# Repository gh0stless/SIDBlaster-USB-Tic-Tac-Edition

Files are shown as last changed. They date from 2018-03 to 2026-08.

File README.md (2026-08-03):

# SIDBlaster-USB Tic Tac Edition

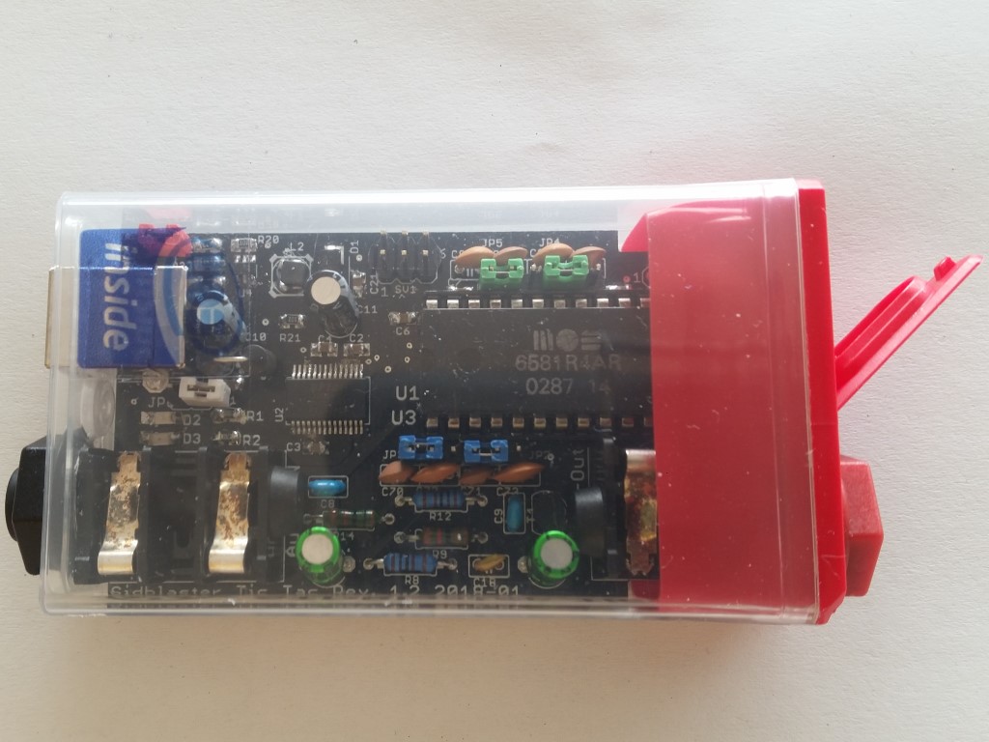
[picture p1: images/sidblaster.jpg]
SIDBlaster-USB Tic Tac Edition


**Open-source USB hardware for a genuine MOS 6581/8582 SID chip** - C64 sound
on real silicon, on your PC's USB port. Small enough to fit in a "Tic Tac"
mint box (hence the name), it plugs into a USB port and appears to host
software as a HardSID-compatible device: play SID tunes with cycle-accurate
hardware sound, or use it as a real analog synth voice from a DAW.

- - -

## What's in the box

- A genuine SID chip (6581 or 8580/8582 - your choice, whatever you socket)
  driven by a Microchip PIC16F886 and an FTDI FT245R USB-to-parallel-FIFO
  bridge
- A 6.3mm (1/4") jack audio output, studio-ready out of the box - unlike
  most RP2040-based SID-USB alternatives
- Open PCB design (Eagle + Gerber), currently at hardware revision **1.5**
- Firmware (MPASM source + compiled HEX) for the PIC16F886
- A 3D-printable case (by tyristori)
- Full German/English assembly instructions, user manual and bill of
  materials

The [driver](https://github.com/gh0stless/SIDBlasterUSB_HardSID-emulation-driver)
supports up to **8** units side by side - handy for multi-SID setups
(stereo/triple-SID playback) and for music-instrument applications like
[AIASS](https://github.com/gh0stless/AIASS-Uno-VST) that want several
independent SID voices at once.

- - -

## Repository layout

| Folder | Contents |
|---|---|
| [`pcb/`](./pcb) | Eagle schematic/board files + Gerbers, revisions 1.2 - 1.5 |
| [`pic16f886/`](./pic16f886) | PIC16F886 firmware - MPASM source and compiled `.hex` |
| [`ftdi_template/`](./ftdi_template) | FT_PROG templates for programming the FT245R USB chip |
| [`docs/`](./docs) | Assembly instructions, user manual, bill of materials (BOM) per revision - PDF + editable ODT/ODS sources |
| [`datasheet/`](./datasheet) | MOS 6581/6582 SID and MT3608 datasheets |
| [`3d_printed_case/`](./3d_printed_case) | 3D-printable case (Blender + STL), CC BY 4.0 |
| [`exSIDBlaster/`](./exSIDBlaster) | How to convert a SIDBlaster-USB into a (single-SID) exSID |
| [`hardsid_library/`](./hardsid_library) | Plain prebuilt `hardsid` driver binaries (Win/Linux/macOS) - see below for the current source/releases |
| [`images/`](./images) | Product photos |

- - -

## Getting started

1. **Build or buy** the hardware - follow the
   [assembly instructions](./docs/assembly%20instructions.pdf) /
   [Aufbauanleitung](./docs/Aufbauanleitung.pdf) and the current
   [BOM (Rev.1.5)](./docs/bill%20of%20materials%20%28BOM%29%20Rev.1.5.pdf).
2. **Program** the PIC (firmware in [`pic16f886/`](./pic16f886)) and the
   FTDI FT245R (template in [`ftdi_template/`](./ftdi_template), via FT_PROG).
3. **Install the driver** - the FTDI D2XX driver plus the `hardsid` HardSID
   emulation library. Get an installer or the latest plain binaries from
   [crazy-midi.de](https://crazy-midi.de) or the driver's own repo, see
   below.
4. **Play something** - any HardSID-aware application (Sidplay2, ACID64,
   VICE, ...) or a purpose-built app such as
   [SIDBlaster ASID Player](https://github.com/gh0stless/SIDBlaster-ASID-Player)
   (turns it into an ASID-protocol MIDI synth) or
   [AIASS](https://github.com/gh0stless/AIASS-Uno-VST) (VST/Standalone
   instrument plugin).

Full details are in the [manual](./docs/SIDBlaster-USB%20Tic%20Tac%20Edition%20User%20Manual.pdf)
/ [Handbuch](./docs/SIDBlaster-USB%20Tic%20Tac%20Edition%20Handbuch.pdf).

- - -

## The software ecosystem

This repo covers the **hardware**. The driver and applications that make it
useful live in their own actively maintained repos:

- **[SIDBlasterUSB_HardSID-emulation-driver](https://github.com/gh0stless/SIDBlasterUSB_HardSID-emulation-driver)** -
  the `hardsid` driver (Windows/Linux/macOS), source + releases. This is
  what any HardSID-compatible application talks to - except ACID64 and
  JSIDPlay2, which bring their own onboard SIDBlaster-USB support.
- **[SIDBlasterTool](https://github.com/gh0stless/SIDBlasterTool)** -
  small device config utility (read/set a device's serial number and SID
  chip type).
- **[SIDBlaster ASID Player](https://github.com/gh0stless/SIDBlaster-ASID-Player)** -
  standalone app that turns the device into an ASID-protocol MIDI synth.
- **[AIASS-Uno-VST](https://github.com/gh0stless/AIASS-Uno-VST)** - VST/VST3/
  Standalone instrument plugin driving the SID chip directly from a DAW.
- **[libsidplayfp](https://github.com/gh0stless/libsidplayfp)** (fork) -
  adds a `sidblaster-builder` backend so any libsidplayfp-based player
  (e.g. [sidplayfp](https://github.com/gh0stless/sidplayfp)) can play SID
  tunes through real SIDBlaster-USB hardware via `hardsid`, on
  Windows and Unix (dlopen).
- **SIDBlaster NG** - a from-scratch firmware + driver stack, built on the
  exSID protocol, for the **existing** SIDBlaster-USB hardware people already
  own - not a new board. Firmware trickery (hybrid mode) runs the exSID
  protocol directly on current hardware, no cutting traces or soldering
  jumpers like the old [exSID conversion](#turning-it-into-an-exsid) needed.
  RP2040-based SID-USB devices (e.g.
  [USBSID-Pico](https://github.com/LouDnl/USBSID-Pico)) may well be where
  the present and future belong for a single device on a desk - but
  SIDBlaster's scalability is unique: several units side by side (see
  [above](#whats-in-the-box)) is exactly what music applications like
  [AIASS](https://github.com/gh0stless/AIASS-Uno-VST) want. NG is planned
  around that: active multi-device handling, hotplug, and resource
  management, not just more units bolted onto the same driver model.

Prebuilt installers for all of the above (handles driver placement,
Linux udev rule, macOS D2XX symlink, etc. for you): **[crazy-midi.de](https://crazy-midi.de)**.

- - -

## Turning it into an exSID

Want [exSID](https://github.com/jpandersen/exSID)-grade playback instead?
See [`exSIDBlaster/`](./exSIDBlaster) for a one-wire hardware hack plus a
firmware/template swap that converts a SIDBlaster-USB into a (single-SID)
exSID-compatible device, for use with e.g. JSIDPlay2. Do-it-yourself, at
your own risk.

- - -

## License

Hardware design and documentation in this repository are licensed under
**GPL v3** (see [`LICENSE`](./LICENSE)). The [`pic16f886/`](./pic16f886)
firmware is **MIT**-licensed. The 3D-printed case files are **CC BY 4.0**
(see [`3d_printed_case/`](./3d_printed_case)). The original exSID firmware
referenced in [`exSIDBlaster/`](./exSIDBlaster) is licensed by the exSID
project under **Creative Commons**, not by this repository.

- - -

## Credits

Designed by Andreas Schumm (gh0stless), crazy-midi.de, building on the
original SIDBlaster concept - whoever first came up with it, thank you,
whoever you are; your name didn't reach me, but the idea did.

Thanks to Stein Pedersen for the original `hardsid` driver, Wilfred Bos for
his help with it and for SIDBlaster-USB support in ACID64Player, and Ken
Händel for the Linux/macOS driver port. exSID conversion notes courtesy of
the exSID project (Thibaut Varène). 3D-printed case by tyristori.

And to my long-time fiancée, Borjana Konstantinowa, for her patience with me.

Andreas Schumm (gh0stless)
contact: info@crazy-midi.de

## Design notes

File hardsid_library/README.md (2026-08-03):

Plain hardsid library binaries (no installer) for SIDBlaster-USB, currently v518 (0x0206).

For the latest version and an installer that handles system placement /
the Linux udev rule / the macOS D2XX symlink for you, see the driver's
own repo instead:

- [gh0stless/SIDBlasterUSB_HardSID-emulation-driver](https://github.com/gh0stless/SIDBlasterUSB_HardSID-emulation-driver) - source, releases, changelog
- Proper installers: [crazy-midi.de](https://crazy-midi.de)

The files here are kept only for the download links already referenced
from AIASS/SIDBlaster-ASID-Player's manuals.

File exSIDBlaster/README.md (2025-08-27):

# exSIDBlaster - a farewell gift

If you want, you can now convert your SIDBlaster into half an exSID.

You may have heard of its near-perfect playback, even of problematic tunes.
The exSID project, started by **Thibaut Varène**, is a further development of the SIDBlaster circuit with truly sophisticated firmware. It was pretty much a Linux standalone product, but later, cross-platform support was offered, at least by JSIDPlay2.

Please also note that neither I nor Thibaut take responsibility for this hack, if YOU do it it is entirely your risk.

After the conversion, you essentially have an exSID but only one SID. You can use this in JSIDPlay2 or the web version. Simply enable "Fake Stereo" and the sound will always play. 

Please note that the exSID firmware is under a Creative Commons license, so I cannot offer you a conversion. Basically, you only need to break one wire and solder another as a bridge. Cut pin 7 of the PIC with a small flat side cutter (or perhaps nail clippers). 2.: Solder a jumper from PIC pin 15 to SID socket pin 5. Then flash the new firmware (hex file) and program the new template (make sure you choose the right one!). You can find out how to do this in the SIDBlaster assembly instructions and manual. 

Theoretically, a similar conversion might work with the SIDBlaster nano, but in practice I would advise against it: The smaller package size of the PIC might not be able to cope as well with the additional thermal load caused by the overclocking.

A hardsid.dll wrapper DLL for exSID is still in the works.

Andreas

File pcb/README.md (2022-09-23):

# eagle and gerber files

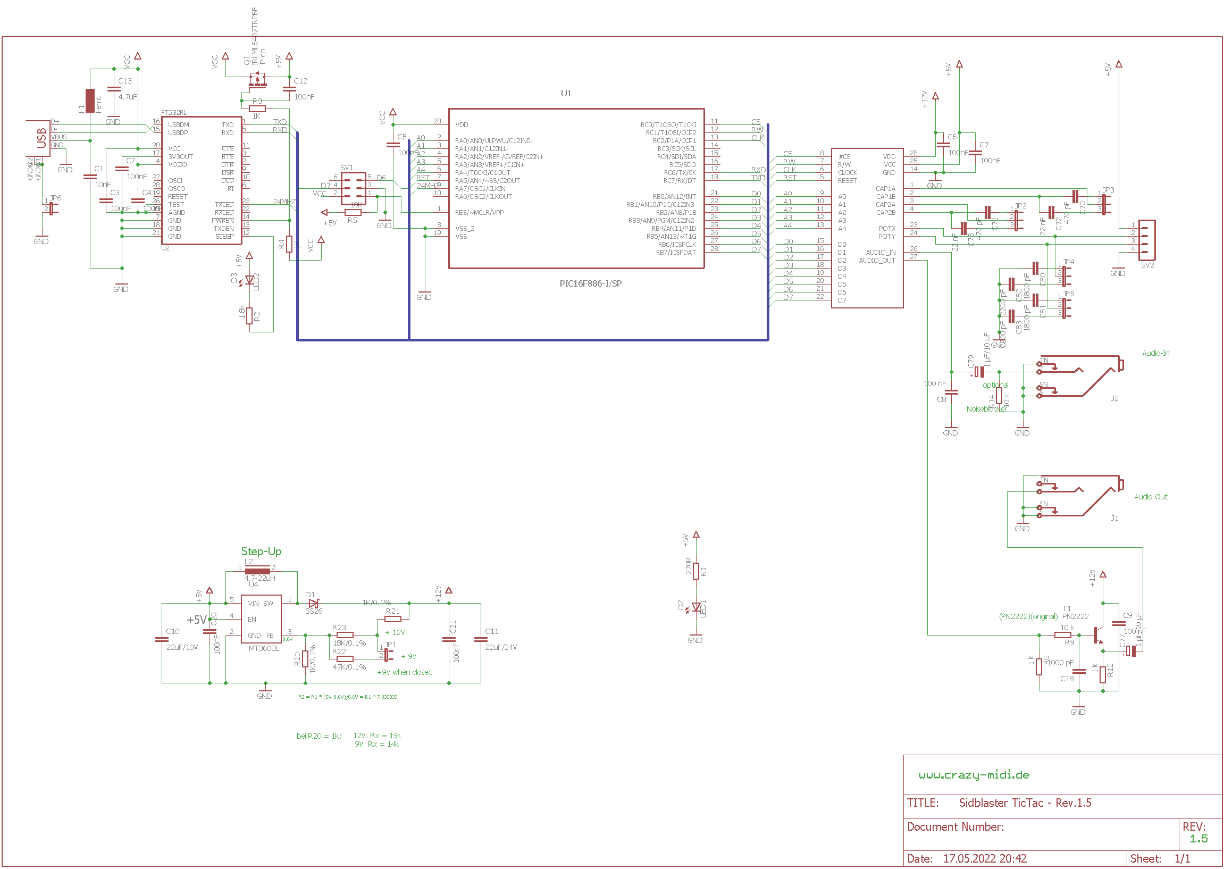
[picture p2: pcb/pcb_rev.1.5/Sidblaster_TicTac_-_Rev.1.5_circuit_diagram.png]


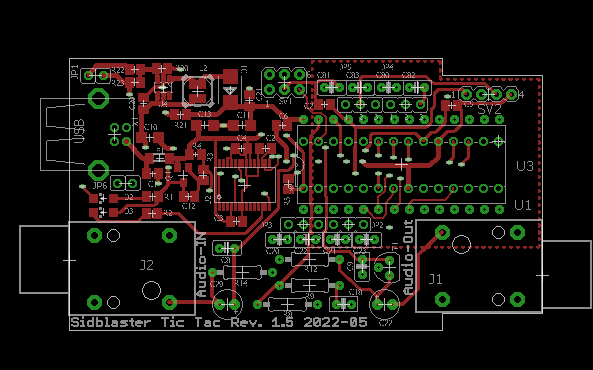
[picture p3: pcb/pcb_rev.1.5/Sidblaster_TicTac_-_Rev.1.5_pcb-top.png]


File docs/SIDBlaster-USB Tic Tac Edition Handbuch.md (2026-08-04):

SIDBlaster-USB Tic Tac Edition

# SIDBLASTER-USB — TIC TAC EDITION

*– Ein echter SID Chip auf PC oder Mac*

## HANDBUCH

von Andreas Schumm, Rev. 1.4

Copyright© 2024 [www.crazy-midi.de](http://www.crazy-midi.de/) – Lizenz: [CC BY-ND 4.0](https://creativecommons.org/licenses/by-nd/4.0/deed.de)

---

# 1. Einführung

Der SIDBlaster-USB Tic Tac ist eine hochwertige "Open-Source"-Hardware, die als kleine, an den USB-Port eines PCs oder Macs anschließbare Box die Nutzung eines echten "SID"-Soundchips zur C64-Emulation, Wiedergabe von SID-Tunes und Musikproduktion ermöglicht.

SIDBlaster-USB Tic Tac basiert auf "SIDBlaster-USB", und ist mit diesem zu 100% kompatibel.

## 1.1 Verbesserungen

- hochwertige Universalstromversorgung 9V oder 12V
- Original C64-Audioverkabelung
- Optionale Anschlussmöglichkeit für zwei Paddles
- Umschaltbare Filterkondensatoren
- Umschaltbare Kondensatoren für Paddle
- Passgenaue Platine zum Einbau in eine Tic Tac Schachtel
- Audio-Eingang
- Professionelle 6,3mm Mono-Audio-Klinkenbuchsen
- Gemütliche blaue Power-LED
- (Rev.1.2:) rote TX/RX-LED
- (Rev. 1.2 weißer Jumper zum Verbinden von GND und Shield (experimentell)
- vorbereitet für Lesezugriff (Firmware 1.1)

# 2. Allgemeine Informationen

- Plug and Play ist nicht möglich, der SIDBlaster muss vor der Verwendung in einer Anwendung an den Computer angeschlossen werden. Trennen Sie den SIDBlaster auch nicht vom Computer, bevor Sie die Anwendung beendet haben.
- Wenn Sie den SIDBlaster nicht benutzen, ist es empfehlenswert, die USB-Verbindung zu trennen, da dies die Lebensdauer des SID-Chips verlängert.
- Da ein SID-Chip Wärme erzeugt, verwenden Sie wenn möglich einen Kühlkörper auf dem Chip und sorgen Sie für ausreichende Belüftung (lassen Sie die Klappe der Tic Tac-Box offen).

# 3. Hardware-Installation

## 3.1 SID-chip-installation

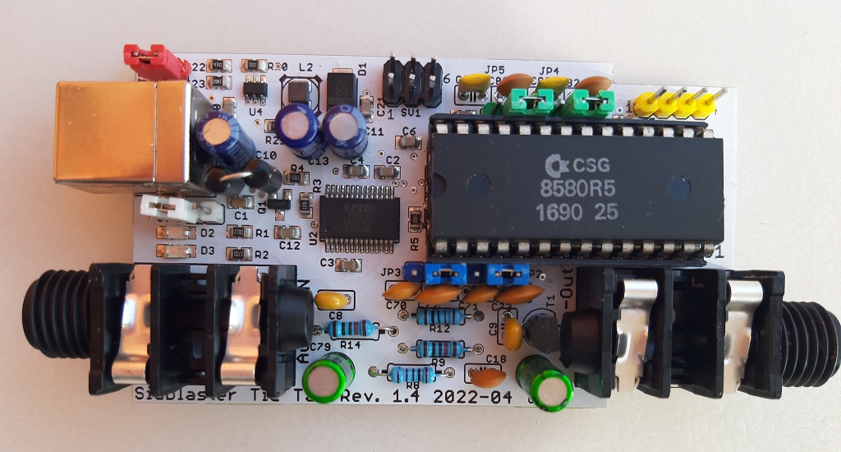
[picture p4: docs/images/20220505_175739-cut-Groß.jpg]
SID-Chip Installation


*Ein SIDBlaster-USB mit korrekt installiertem 8580*

**Warnung!** Überprüfen Sie die Spannungseinstellungen an der SIDBlaster-Hardware. Wenn Sie sie falsch einstellen, z.B. wenn Sie 12V in einen 8580 SID-Chip schicken, der mit 9V läuft, werden Sie den Chip zerstören. Wenn Sie ein Multimeter haben, **prüfen Sie die Spannung an der SID-Chip-Buchse**, um sicherzugehen. Verwenden Sie immer ESD-Schutz (z.B. ein Antistatik-Armband), um den SID-Chip und andere elektrische Komponenten nicht zu beschädigen, wenn Sie ihn in den SIDBlaster einbauen.

**Um einen SID-Chip zu entfernen**, verwenden Sie z.B. einen Schraubendreher, hebeln Sie den Chip abwechselnd heraus. Achten Sie darauf, die Platine oder die Bauteile nicht zu beschädigen.

Vor dem Einsetzen eines SID-Chips biegen Sie die Pins mit einer Zange gerade, drücken Sie vorsichtig und überprüfen Sie, dass keiner der Pins umknickt.

## 3.2 Jumper-Einstellungen

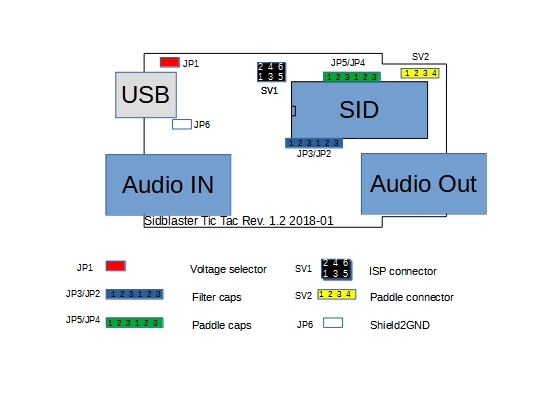
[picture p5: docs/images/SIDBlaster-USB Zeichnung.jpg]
Jumper-Übersicht


### 3.2.1 Für den 6581 SID-chip:

- JP1: muss offen sein (12V).
- JP2-JP5: Setzen Sie alle Jumper auf die linke Seite (Stifte 1-2).

### 3.2.2 Für den 8580 SID-chip:

- JP1: muss geschlossen sein (9V).
- JP2-JP5: Setzen Sie alle Jumper auf die rechte Seite (Stifte 2-3).

## 3.3 Andere Jumper der Hardware

### 3.3.1 JP6 (Weiss)

Ab Rev. 1.2 und höher. Experimentell, verbindet die USB-Abschirmung mit Masse; Sie können es benutzen, um Störgeräuschen entgegenzuwirken.

### 3.3.2 SV2:Paddle-Anschluss (gelb)

Hier haben Sie Zugriff auf die beiden A/D-Wandler des SID-Chips. Sie können z.B. 2 Drehpotentiometer als Paddles anschließen. Dies ist vor allem für Programmierer interessant. Sie können die Funktion auch mit dem SID-Objekt für Max/MSP verwenden.

| Pin | Funktion |
|---|---|
| 1 | +5V |
| 2 | POTX |
| 3 | POTY |
| 4 | GND |

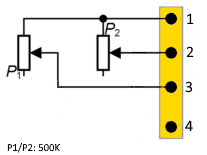
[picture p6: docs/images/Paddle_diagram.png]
Paddle-Anschluss Diagramm


### 3.3.3 SV1: ISP Connector

Verwenden Sie einen Picit 3 Programmer, um den Flash-Speicher des Mikrocontrollers zu programmieren. Als Software wird MPLAB IPE verwendet.

| Pin | Funktion |
|---|---|
| 1 | MCLR/VPP |
| 2 | +5V |
| 3 | GND |
| 4 | PGD (ICSPDAT) |
| 5 | PGC (ICSPCLK) |
| 6 | n.c. |

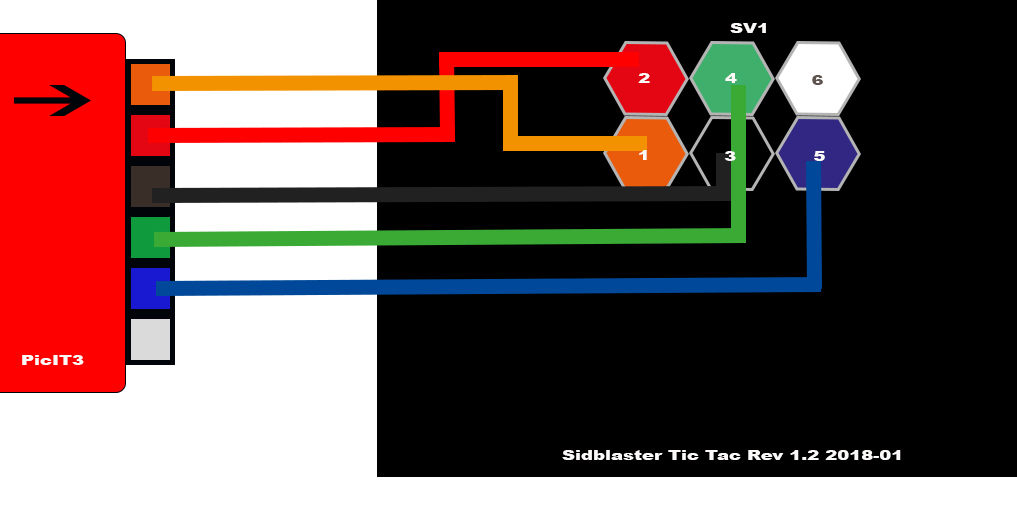
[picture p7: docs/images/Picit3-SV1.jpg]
SV1 ISP Connector Verkabelung


## 3.4 USB- und Audioanschlüsse

### 3.4.1 USB-Anschluss

Schließen Sie die SIDBlaster-Hardware mit einem USB-Kabel vom Typ A-B von guter Qualität an einen USB-Port an. Die Hardware kann auch mit einem USB-Hub guter Qualität funktionieren.

### 3.4.2 Audio-Ausgangsbuchse

Der Audioausgang ist als professionelle 6,3mm-Klinkenbuchse ausgeführt. Verbinden Sie den Audio-Ausgang des SIDBlaster mit Ihrem Mischpult oder Audio-Interface mit einem unsymmetrischen (Mono) Kabel.

### 3.4.3 Audio-Eingangsbuchse

Die zweite Audiobuchse am SIDBlaster ist ein Audioeingang und ist ebenfalls ein unsymmetrischer Anschluss. Wenn Sie sich nicht sicher sind, welcher Anschluss welcher ist, sind die Anschlüsse auf der Platine markiert. Seien Sie vorsichtig, was Sie an den Eingang des SID-Chips anschließen. Diese Chips sind alt und sehr empfindlich gegenüber Spannungsspitzen und zu hohen Spannungen.

## 3.5 exSIDBlaster (optionaler Firmware-Hack)

Wer möchte, kann seinen SIDBlaster mit einem kleinen Hardware-Eingriff und neuer Firmware in einen Teil eines exSID umwandeln – ein Projekt von Thibaut Varène mit besonders ausgereifter, zyklengenauer Firmware. Nach der Umwandlung steht effektiv ein exSID mit einem SID-Chip zur Verfügung, nutzbar z.B. mit JSIDPlay2 (dort „Fake Stereo" aktivieren).

Dies ist ein experimenteller Umbau auf eigene Verantwortung – weder Andreas Schumm noch Thibaut Varène übernehmen dafür Haftung. Details zur genauen Durchführung (PIC-Pin 7 durchtrennen, Brücke von PIC-Pin 15 zu SID-Sockel-Pin 5 löten, neue Firmware flashen) finden Sie im exSIDBlaster-Ordner des SIDBlaster-USB-Tic-Tac-Edition-Repositories.

# 4. Software

## 4.1 Der FTDI D2XX Treiber

### 4.1.1 Windows

Der SIDBlaster muss einen digitalen "Handshake" durchführen, wenn er zum ersten Mal über USB angeschlossen wird. Dies erfordert eine Internetverbindung. Der Handshake funktioniert nicht, wenn Ihre Internetverbindung in Windows auf "Getaktete Verbindung" eingestellt ist. Um dieses Problem zu lösen, deaktivieren Sie vorübergehend die "Getaktete Verbindung", warten Sie einen Moment, bis der SIDBlaster den Handshake durchführt, und aktivieren Sie die "Getaktete Verbindung" anschließend wieder.

Die neuesten Windows-Versionen stellen den FTDI-Treiber über die Update-Funktion zur Verfügung. Prüfen Sie also: Einstellungen / Updates / Optionale Updates.

Der SIDBlaster wird von Windows als "USB Serial Converter" erkannt. Er kann (im Gerätemanager) als COMx Gerät mit Ports erkannt werden. Edit: Ihr SIDBlaster muss in diesem Fall mit dem FTDI prog Tool und dem Template aus dem SIDBlaster Projekt korrekt geflasht werden. Die aktuelle hardsid.dll akzeptiert keine falsch geflashten SIDBlaster.

Bei älteren Windows-Versionen kann die Installation eines Treibers von FTDI notwendig sein, erhältlich bei: <http://www.ftdichip.com/Drivers/D2XX.htm>

### 4.1.2 Linux

Downloaden Sie den D2XX Treiber von: <https://ftdichip.com/drivers/d2xx-drivers/>

Bitte installieren Sie FTDI Treiber so, wie es im Kapitel 2 "Installing the D2XX driver" hier erklärt wird: <https://www.ftdichip.com/Support/Documents/AppNotes/AN_220_FTDI_Drivers_Installation_Guide_for_Linux.pdf>

Wenn das Gerät immer noch nicht verwendet werden kann, installieren Sie bitte die in Kapitel '1.1 Overview' beschriebene Abhilfe:

```
$ sudo vi /etc/udev/rules.d/91-sidblaster.rules

ACTION=="add", ATTRS{idVendor}=="0403", ATTRS{idProduct}=="6001", MODE="0666", RUN+="/bin/sh -c 'rmmod ftdi_sio && rmmod usbserial'"

$ sudo udevadm control --reload-rules && udevadm trigger
```

### 4.1.3 MacOS

Hinweis: Es kann notwendig sein, die Sicherheitsüberwachung in MacOS auszuschalten oder alle Entwickler zu autorisieren.

```
sudo spctl --master-disable
```

Könnte auch funktionieren:
```
sudo xattr -rd com.apple.quarantine / Your software path.app
```

Downloaden und installieren Sie den D2XX Treiber von: <https://ftdichip.com/drivers/d2xx-drivers/>

Folgen Sie den Instruktionen von: <https://ftdichip.com/wp-content/uploads/2020/08/AN_134_FTDI_Drivers_Installation_Guide_for_MAC_OSX-1.pdf>

Downloaden und installieren Sie D2XXHelper von derselben Website.

## 4.2 Die hardsid Library (hardsid.dll)

Ist sozusagen der "Treiber" bzw. die "Middleware" des SIDBlasters. Unter Windows besteht er aus einer umprogrammierten DLL des Hardsid, so dass Software, die für den Hardsid programmiert wurde, mit dem SIDBlaster kompatibel ist. Später wurde die DLL auch auf Linux und Macos portiert. Die DLL wird von Stein Pedersen erstellt und gepflegt. Die Linux/Mac Portierung wurde von Ken Händel erstellt.

### 4.2.1 Windows

- Download von: <https://crazy-midi.de/joomla/index.php/mydownloads>
- Empfehlung: Installieren Sie den Treiber über sein eigenes Installationsprogramm (installiert die DLL systemweit unter Windows\System32). Alternativ können Sie die passende hardsid.dll auch manuell in das Programmverzeichnis eines einzelnen Programms kopieren.
- Die 64-Bit-Version wird von der 64-Bit-Version von Vice sowie von den 64-Bit-Versionen von AIASS benötigt.

### 4.2.2 Linux

- Downloaden Sie von: <https://crazy-midi.de/joomla/index.php/mydownloads>
- Kopieren Sie libhardsid.so in /usr/local/lib/
- Wenden Sie chmod 0755 bei libhardsid.so an
- Kopieren Sie hardsid.hpp to /usr/local/include/

### 4.2.3 MacOS

- Downloaden Sie von: <https://crazy-midi.de/joomla/index.php/mydownloads>
- Kopieren Sie libhardsid.dylib in /usr/local/lib/
- Kopieren Sie hardsid.hpp nach /usr/local/include/

### 4.2.4 SIDBLASTERUSB_WRITEBUFFER

Abhängig von Ihrem System können Musikstücke mit hohen Datenraten (Multispeed-Tunes oder Digitunes) langsamer abgespielt werden, wenn die Latenzzeit des USB-Treibers zu hoch ist. Dies kann behoben werden, indem die Größe des Schreibpuffers des Treibers auf einen größeren Wert gesetzt wird, zum Beispiel. Auf schnellen Rechnern funktioniert das sogar bis auf 0.

#### 4.2.4.1 Windows
```
set SIDBLASTERUSB_WRITEBUFFER_SIZE=8
```

#### 4.2.4.2 Linux/MacOS
```
export SIDBLASTERUSB_WRITEBUFFER_SIZE=8
```

## 4.2.5 Das SIDBlasterTool

Mit dem SIDBlasterTool können Sie überprüfen, ob die Kommunikation zwischen Bibliothek und Gerät funktioniert.

Sie können auch den SID-Typ einstellen und die Seriennummer ändern. Der Typ wird als Teil der Gerätebeschreibung gespeichert und von Anwendungen wie JSIDPlay ausgewertet.

Das SIDBlasterTool ist Teil des Treiber-Pakets: <https://crazy-midi.de/joomla/index.php/mydownloads>

## 4.2.6 Hinweise für Entwickler

Für Entwickler, die Anwendungen unter Verwendung der hardsid-Bibliothek schreiben wollen, verweise ich auf hardsid.hpp sowie auf integrators_guide.md (liegt dem Treiber-Installationsprogramm bei). Der Quellcode des Treibers liegt hier: <https://github.com/gh0stless/SIDBlasterUSB_HardSID-emulation-driver>. Weitere Tipps finden Sie im AIASS-VST Repository im Ordner doc. Vergessen Sie nicht, die destructor-Methode beim Beenden unter MacOS und Linux manuell aufzurufen.

Eine ausführliche Anleitung zur Erstellung der hardsid-Bibliothek finden Sie hier (dank Ken Handel): <https://haendel.ddns.net/~ken/sidblaster.html>

## 4.3 Anwendungen

### 4.3.1 Vice64

Der berühmte C64-Emulator unterstützt bis zu 3 SIDBlaster. Im einfachsten Fall haben Sie nun einen C64 mit Originalsound. Sie können den SIDBlaster aber auch mit Vice64 als MIDI-Expander verwenden, indem Sie die MIDI-Emulation aktivieren und ein Synthesizer-Programm wie Station64 laden. (Nur für Windows).

### 4.3.2 ACID64 Player

Beste SIDBlaster-Unterstützung. Wenn Sie mehrere Geräte besitzen, können Sie sogar Stereo- und 3SID-Musik abspielen. Nur Windows. Wieder SIDBlaster-Unterstützung ab Version 4.3. Seit dieser Version spricht ACID64 den SIDBlaster direkt an – die hardsid-Bibliothek wird nicht mehr benötigt.

### 4.3.3 SidPlay2

Guter SID-Player, durch Wiedergabelisten auch als Jukebox geeignet. Nur für Windows.

### 4.3.4 GoatTracker

Tracker. Unterstützt einen oder zwei SIDBlaster. Nur für Windows.

### 4.3.5 JSIDPlay2

JSIDPlay2 ist ein fantastischer C64 Content Media Player. In der aktuellen Version bietet es die beste SIDBlaster-Unterstützung. Er ist vielleicht nicht ganz so handlich wie ACID64, aber wenn man sich einmal damit vertraut gemacht hat, ist es ein sehr leistungsfähiges und umfassendes Programm. Erhältlich für Windows, MacOS und Linux.

JSIDPlay2 unterstützt den SIDBlaster von Haus aus, lediglich Java ist erforderlich. Es ist somit nicht notwendig, D2XX-Treiber oder die hardsid-Bibliothek zu installieren.

#### 4.3.5.1 JSIDPlay2 Android app

Verwandeln Sie mit dieser App ihr Mobiltelefon in einen mobilen SIDPlayer. Verbinden Sie Ihren SIDBlaster mit Ihrem Mobiltelefon. Sie benötigen einen OTG-USB-Adapter und wahrscheinlich einen Mono-Stereo-Adapter für die Kopfhörer.

### 4.3.6 CloanTo's C64 Forever

Ebenfalls kompatibel. Kopieren Sie einfach die hardsid.dll in den Ordner von Vice (Help/About/VICE Plugin, Open File Location).

Dann geben Sie "-sidenginemodel hardsid" in der Option "custom parameters" (in Tools/Options/Emulation, in Plugins/VICE/Custom parameters...) ein.

### 4.3.7 AIASS

AIASS Is A SID Synthesizer

#### 4.3.7.1 sid-object for Max/MSP & Max4Live

Ist ein Max/MSP C-external für den SIDBlaster-USB.

#### 4.3.7.2 AIASS – Max4Live Gerät(e)

Der AIASS for MAX4LIVE ist ein Set von max4live Geräten, um einen oder mehrere SIDBlaster-USB als Synthesizer-Anwendung zu steuern. Dies macht es möglich, Musik mit einem originalen SID-Chip MOS 6581 oder MOS 8580 aus dem Commodore 64, in einer modernen DAW zu produzieren.

#### 4.3.7.3 AIASS – VST

AIASS als VST (auf allen Systemen)

### 4.3.8 ASID Protokoll Player

Kleines Programm mit dem man ASID MIDI Datenströme auf dem SIDBlaster wiedergeben kann. Unterstützt bis zu 3 SIDBlaster für 2SID und 3SID Tunes. Damit können sie zum Beispiel den Payer der Webseite DeepSID nutzen.

# 5. Betrieb mehrerer Geräte

Sie können mehrere SIDBlaster-USB gleichzeitig verwenden.

Dies wird von ACID Player, JSIDPlay2, Vice, Goattracker und AIASS unterstützt.

Der Vorteil liegt in der Wiedergabe von Stereo- oder 3Sid-Tunes, Fake-Stereo, automatischer Auswahl des richtigen SID-Typs mit JSIPlay2 (Typ mit dem SIDBlastertool einstellen), oder mehrerer Instrumente mit AIASS (noch nicht beim VST).

# 6. Links

- <http://crazy-midi.de/>
- <https://github.com/gh0stless/SIDBlaster-USB-Tic-Tac-Edition>
- <https://github.com/gh0stless/SIDBlasterTool>
- <https://github.com/gh0stless/SIDBlaster-ASID-Player>
- <https://github.com/gh0stless/AIASS-for-MAX4LIVE>
- <https://github.com/gh0stless/AIASS-Uno-VST>
- <https://github.com/gh0stless/SIDBlasterUSB_HardSID-emulation-driver>
- <https://vice-emu.sourceforge.io/>
- <https://www.acid64.com>
- <http://www.gsldata.se/c64/spw/> (SIDPlay2)
- <https://haendel.ddns.net/~ken/> (JSIDPlay2)
- <https://sourceforge.net/projects/goattracker2/>
- <https://www.facebook.com/groups/2305052182957954/>

# 7. Danksagungen

- Davey (The Phantom) für die Erstellung des ursprünglichen SIDBlasters.
- Stein Pedersen für die Unterstützung und die sidblaster.dll.
- Wilfred Bos für seinen ACID Player und Tipps und Hilfe.
- Ken Händel für den POSIX Port und seine Arbeit an der Bibliothek
- Karl-Werner Riedel für seine Hilfe bei der Entwicklung der Tic Tac Hardware.
- Magnus Hansson für das Schreiben einiger Originalteile dieses Handbuchs.
- Yvonne Hölzel für Revision und Übersetzungen.
- Ein spezieller Dank an Thibaut VARÈNE, für seinen exSID und seine tolle Firmware, die mit einem Hack auch mit dem SIDBlaster verwendet werden kann.
- Borjana Konstantinowa für ihre Geduld mit mir.

Coswig, Sachsen 04/08/26

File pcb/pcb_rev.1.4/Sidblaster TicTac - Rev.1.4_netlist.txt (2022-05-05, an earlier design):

Netlist

Exported from Sidblaster TicTac - Rev.1.4.brd at 12.04.2022 13:38

EAGLE Version 7.7.0 Copyright (c) 1988-2016 CadSoft

Net      Part     Pad

+5V      C10      +
         C12      1
         C20      2
         C7       1
         D3       A
         L2       1
         Q1       3
         R1       2
         R5       1
         SV2      1
         U3       25
         U4       4
         U4       5

+12V     C11      +
         C21      2
         C6       1
         C9       1
         D1       C
         R21      1
         T1       3
         U3       28

24MHZ    U1       9
         U2       23

A0       U1       2
         U3       9

A1       U1       3
         U3       10

A2       U1       4
         U3       11

A3       U1       5
         U3       12

A4       U1       6
         U3       13

CLK      U1       13
         U3       6

CS       U1       11
         U3       8

D0       U1       21
         U3       15

D1       U1       22
         U3       16

D2       U1       23
         U3       17

D3       U1       24
         U3       18

D4       U1       25
         U3       19

D5       U1       26
         U3       20

D6       SV1      5
         U1       27
         U3       21

D7       SV1      4
         U1       28
         U3       22

GND      C1       2
         C10      -
         C11      -
         C13      -
         C18      1
         C2       2
         C20      1
         C21      1
         C3       2
         C4       2
         C5       2
         C6       2
         C7       2
         C8       1
         C80      2
         C81      2
         C82      2
         C83      2
         C9       2
         D2       C
         J1       S
         J1       SN
         J2       S
         J2       SN
         J2       TN
         JP6      2
         R12      2
         R14      1
         R20      2
         R8       2
         SV1      3
         SV2      4
         U1       19
         U1       8
         U2       18
         U2       21
         U2       25
         U2       26
         U2       7
         U3       14
         U4       2
         X1       GND

N$1      C79      +
         C8       2
         U3       26

N$2      U2       15
         X1       D+

N$3      C79      -
         J2       T
         R14      2

N$4      C71      1
         JP2      1

N$5      R8       1
         R9       2
         U3       27

N$6      JP1      1
         R21      2
         R23      2

N$7      C71      2
         C73      2
         U3       4

N$8      C73      1
         JP2      3

N$9      JP2      2
         U3       3

N$10     C70      2
         C72      2
         U3       2

N$11     C70      1
         JP3      1

N$12     C72      1
         JP3      3

N$13     JP3      2
         U3       1

N$14     JP4      2
         SV2      2
         U3       23

N$15     U2       16
         X1       D-

N$16     R5       2
         SV1      1
         U1       1

N$17     JP5      2
         SV2      3
         U3       24

N$18     C77      -
         J1       T

N$19     C18      2
         R9       1
         T1       2

N$20     C77      +
         R12      1
         T1       1

N$21     D1       A
         L2       2
         U4       1

N$22     JP1      2
         R22      2

N$23     D2       A
         R1       1

N$24     D3       C
         R2       2

N$25     C1       1
         F1       1
         X1       VBUS

N$26     C80      1
         JP4      1

N$27     C82      1
         JP4      3

N$28     C2       1
         U2       17

N$29     JP6      1
         X1       GND@1
         X1       GND@2

N$30     C81      1
         JP5      1

N$31     C83      1
         JP5      3

N$32     C12      2
         Q1       1
         R3       2

PWREN    R3       1
         R4       2
         U2       14

PWRLED   R2       1
         U2       12

R22      R20      1
         R22      1
         R23      1
         U4       3

RST      U1       7
         U3       5

RW       U1       12
         U3       7

RXD      U1       17
         U2       5

TXD      U1       18
         U2       1

VCC      C13      +
         C3       1
         C4       1
         C5       1
         F1       2
         Q1       2
         R4       1
         SV1      2
         U1       20
         U2       20
         U2       4

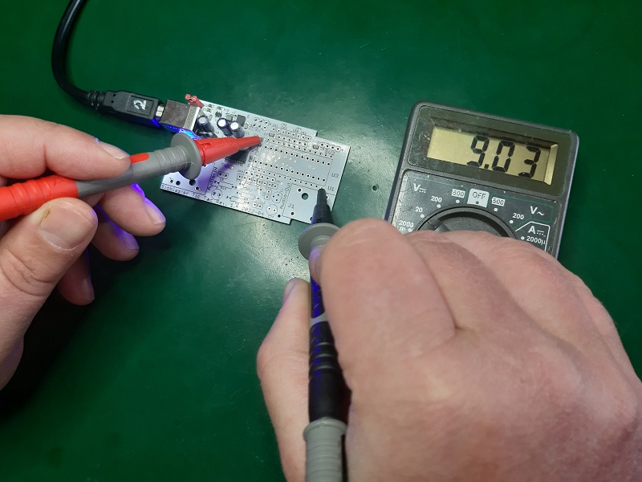
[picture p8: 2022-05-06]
docs/images/20220504_192409-Mittel.jpg

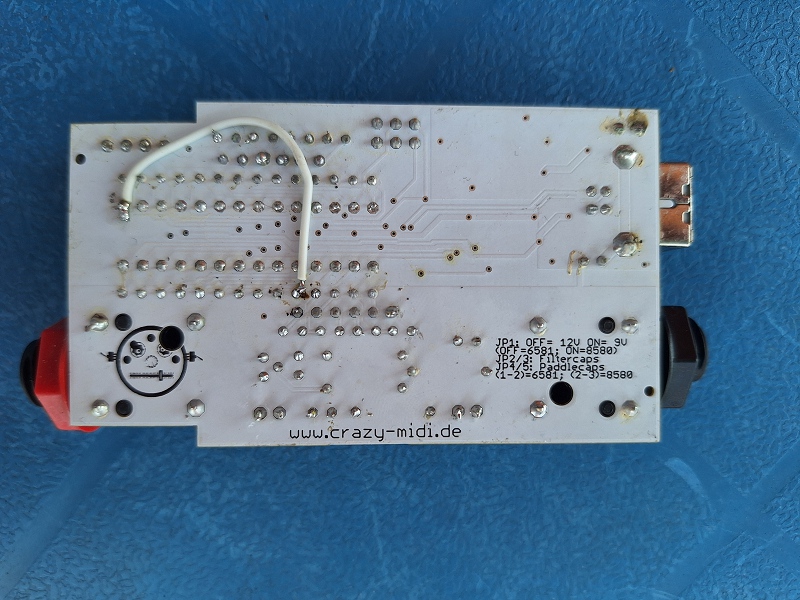
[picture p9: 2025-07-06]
exSIDBlaster/images/20250625_110948-Mittel.jpg

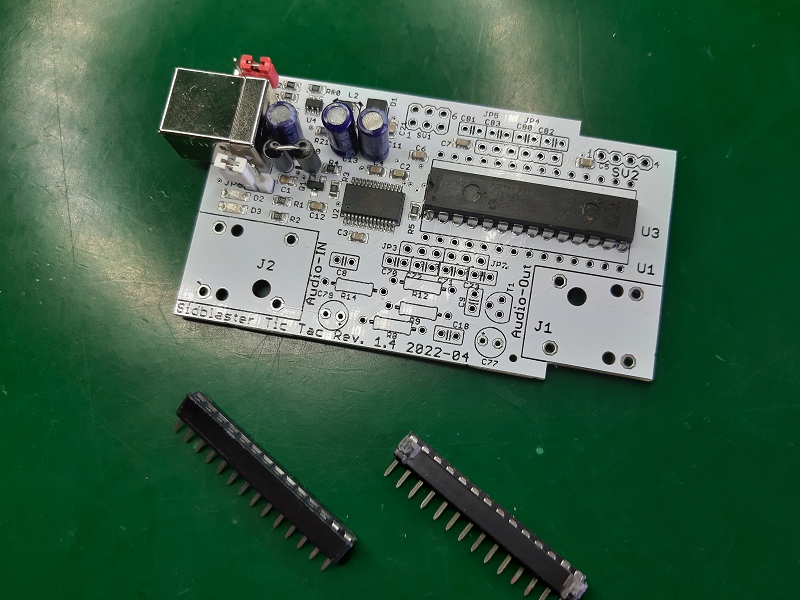
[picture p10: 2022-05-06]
docs/images/20220505_122602-Mittel.jpg

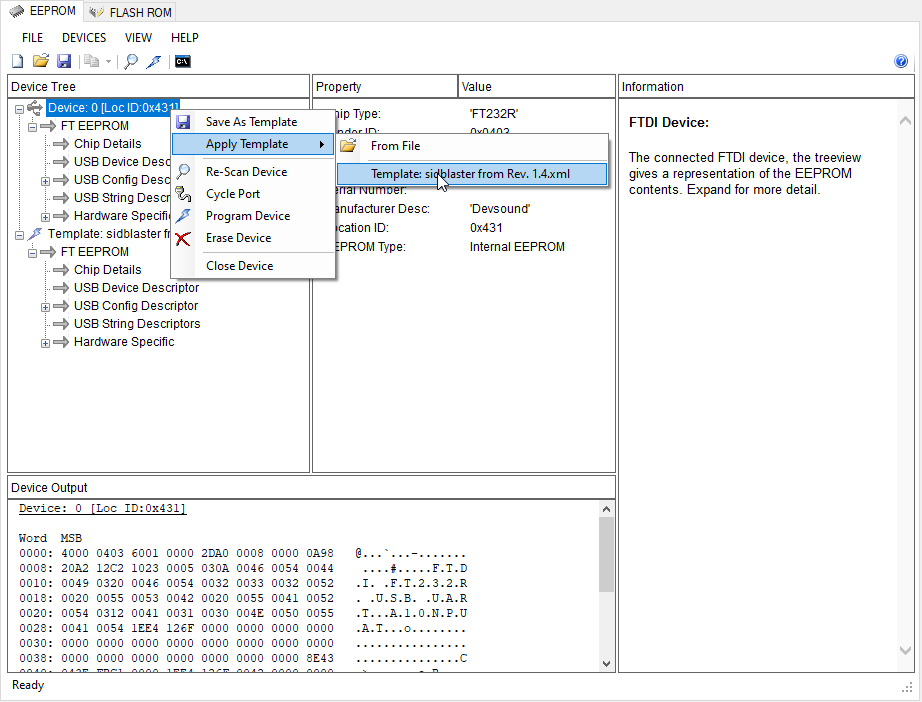
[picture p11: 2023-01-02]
docs/images/FT_Prog_2023-01-02_10-01-42.png

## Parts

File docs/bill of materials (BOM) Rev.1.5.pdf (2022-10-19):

bill of materials (BOM) Sidblaster Tic-Tac (Rev.1.3)
part | description | quantity design | remark | Reichelt
U1 | PIC 16F886-I/SP | 1 S-DIL-28 | 8-bit PICmicro microcontroller, 14 KB, 20 MHz, SDIP-28 | PIC 16F886-I/SP
U2 | FT232RL | 1 SSOP 28 | RS232 interface bridge, USB to UART, SSOP-28 | FT 232 RL
U3 | MOS 6581 or 8580 | 1 DIL-28 | C64 Sound Interface Device SID | -
U4 | MT3608 | 1 6-pin SOT-23 | Power Step-Up | -
L1 (F1) | Ferrit | 1 SM-1206 | Ferrit
L2 | 4,7-22µH/1.2MHz | 1 FPS | | L-1212FPS 10µ
Q1 | IRLML6402TRPBF | 1 SOT23 | IRLML 6402 MOSFET, P-Kanal, -20 V, -3,7 A, Rds(on) 0,065 Ohm, SOT-23 | IRLML 6402
C1 | 10nF | 1 0805 | | X7R-G0805 10N
C2,C3,C4,C5,C6,C7,C12,C20,C21 100nF | 9 0805 | X7R-G0805 100N
C8, C9 | 100nF | 2 25x50 | | KERKO 100N
C18 | 1000pF | 1 25x50 | | KERKO 1,0N
C13 | 4,7µF | 1 C1206 | Electrolytic capacitor 4,7µF
C10 | 22µF/10V | 1 C1206 | Electrolytic capacitor 22µF/10V
C11 | 22µF/24V | 1 C1206 | Electrolytic capacitor 22µF/24V
C77,C79 | 10µF | 2 E2,5-5 | Bipolar, Audio, 25V, NICHICON UES1E100MDM1TD | Ali Express
C70,C71 | 470pF | 2 25x50 | | KERKO 470P
C72,C73 | 22nF | 2 25x50 | | KERKO 22N
C82,C83 | 2200pF | 2 25x50 | | KERKO 2,2N
C80,C81 | 1800pF | 2 25x50 | | KERKO 1,8N
R1, R2 | 270R | 2 0805 | | SMD-0805 270
R3,R4 | 1k | 2 0805 | SMD chip resistor, type 0805, 1k | PAN ERJP06F1001
R5 | 10k | 1 0805 | SMD chip resistor, type 0805, 10k | PAN ERJP06F1002
R9,R14 | 10k | 2 207/10 | Metal oxide resistor 1 W, 5%, 10 kOhm | 1/4W 10K
R8,R12 | 1k | 2 207/10 | Metal oxide resistor 1 W, 5%, 1.0 kOhm | 1/4W 1,0K
R20,R21 | 1k | 2 0805 | SMD chip resistor 0805, 1.0 kOhms, 0.1% | SPR-0805 1,00K
R22 | 47k | 1 0805 | SMD chip resistor 0805, 47.0 kOhms, 0.1% | SPR-0805 47,0K
R23 | 18k | 1 0805 | SMD chip resistor 0805, 18.0 kOhms, 0.1% | SPR-0805 18,0K
J1,J2 (Audio-Jack) | NEUTRIK NR-J4HF | 2 | | NEUTRIK NR-J4HF
Screw Nut Red | NEUTRIK NR-JNUTR | 1 | Neutrik mounting nut, red | NEUTRIK NR-JNUTR
Screw Nut Black | NEUTRIK NR-JNUTB | 1 | Neutrik mounting nut, black | NEUTRIK NR-JNUTB
X1 (USB) | LUM 2411-02 | 1 | USB panel-mounted coupler, type B, angled, PCB | LUM 2411-02
D1 | SS26 | 1 DO-214AB/SMC SMD Schottky diode, DO214AC, 60 V, 2 A | SK 26A SMD
LED 1 | SMD LED Blue | 1 1206 | LED, SMD 1206, 285 mcd, blue | LED EL 1206 BL
LED 2 | SMD LED Red | 1 1206 | LED, SMD 1206, 140 mcd, red | LED EL 1206 RT

10µ Chip inductor, 1212FPS, 10 µH

SMD multilayer ceramic capacitor 10 N, 10% SMD multilayer ceramic capacitor 100 N, 10% Ceramic capacitor 100 N
Ceramic capacitor 1.0 N

Ceramic capacitor 470 P
Ceramic capacitor 22 N
Ceramic capacitor 2.2 N
Ceramic capacitor 1.8 N
SMD chip resistor, type 0805, 270 Ohm

Neutrik jack socket, 6.35 mm, mono, slim

T1 | PN2222
1 TO92 | NPN TO-92 transistor 40 V 0.6 A 0.625 W | PN 2222A
IC Base | IC Base 28-Pin
1 DIL-28 | IC socket, 28-pin, double spring contact | GS 28
JP1 | Stripe 2,54mm red
1 2,54mm | Pin headers 2.54 mm, 1X2, straight red | Ali Express
JP2, JP3 | Stripe 2,54mm blue
1 2,54mm | Pin headers 2.54 mm, 1X6, straight blue | Ali Express
JP4, JP5 | Stripe 2,54mm green
1 2,54mm | Pin headers 2.54 mm, 1X6, straight green | Ali Express
JP6 | Stripe 2,54mm white
1 2,54mm | Pin headers 2.54 mm, 1X2, straight white | Ali Express
SV1 | Stripe 2,54mm black
1 2,54mm | Pin headers 2.54 mm, 2X03, straight black | Ali Express
SV2 | Stripe 2,54mm yellow
1 2,54mm | Pin headers 2.54 mm, 1X04, straight yellow | Ali Express
Jumper Blue | Jumper Blue
2 2,54mm | Jumper, blue, RM 2.54, gold-plated | JUMPER 2,54 BL
Jumper Green | Jumper Green
2 2,54mm | Jumper, green, RM 2.54, gold-plated | JUMPER 2,54 GN
Jumper Red | Jumper Red
1 2,54mm | Jumper, red, RM 2.54, gold-plated | JUMPER 2,54 RT
Jumper White | Jumper White
1 2,54mm | Jumper 2.54 mm, open, yellow | MPE 149-1-002-F4

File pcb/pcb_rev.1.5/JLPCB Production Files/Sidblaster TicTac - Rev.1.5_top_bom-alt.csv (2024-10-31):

Comment | Designator | Footprint | LCSC Part #
270R | R1 R2 | M0805 | C17590
1K | R3 R4 | M0805 | C17513
10K | R5 | M0805 | C17414
1K/0.1% | R20 R21 | M0805 | C17513
47K/0.1% | R22 | M0805 | C17713
18K/0.1% | R23 | M0805 | C17506
10nF | C1 | C0805K | C1710
100nF | C2 C3 C4 C5 C6 C7 C12 C20 C21 | C0805K | C49678
22uF/10V | C10 | C1206 | C5672
22uF/24V | C11 | C1206 | C12891
4.7uF | C13 | C1206 | C13983
Ferrit | F1 | SM-1206 | C39279
4.7-22uH | L2 | FPS | C90321
IRLML6402TRPBF | Q1 | SOT23 | C2593
SS26 | D1 | SMB | C511852
LED1 | D2 | CHIPLED_1206 | C131245
LED2 | D3 | CHIPLED_1206 | C93133
FT232RL | U2 | SSOP28-LD | C8690
MT3608L | U4 | SOT23-6 | C2932326

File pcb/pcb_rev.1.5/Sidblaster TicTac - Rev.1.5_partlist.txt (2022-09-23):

Partlist

Exported from Sidblaster TicTac - Rev.1.5.brd at 23.09.2022 12:25

EAGLE Version 7.7.0 Copyright (c) 1988-2016 CadSoft

Assembly variant: 

Part     Value          Package           Library               Position (mil)        Orientation

C1       10nF           C0805K            rcl                   (555 1045)            R0
C2       100nF          C0805K            rcl                   (1307.04724 1215)     R180
C3       100nF          C0805K            rcl                   (1112.04724 730)      R0
C4       100nF          C0805K            rcl                   (1147.04724 1215)     R180
C5       100nF          C0805K            rcl                   (2545 1500)           R0
C6       100nF          C0805K            rcl                   (1415 1370)           R180
C7       100nF          C0805K            rcl                   (1697.40157 1506.5748) R180
C8       100 nF         C025-025X050      rcl                   (1050 550)            R0
C9       100 nF         C025-025X050      rcl                   (1950 425)            R270
C10      22uF/10V       C1206             rcl                   (535 1285)            R0
C11      22uF/24V       C1206             rcl                   (1150 1370)           R180
C12      100nF          C0805K            rcl                   (795.27559 893.70079) R0
C13      4.7uF          C1206             rcl                   (901.5748 1370.07874) R0
C18      1000 pF        C025-025X050      rcl                   (1825 175)            R180
C20      100nF          C0805K            rcl                   (492.5 1515)          R270
C21      100nF          C0805K            rcl                   (1195 1535)           R270
C70      470 pF         C025-025X050      rcl                   (1400 605)            R0
C71      470 pF         C025-025X050      rcl                   (1785 605)            R0
C72      22 nF          C025-025X050      rcl                   (1590 605)            R180
C73      22 nF          C025-025X050      rcl                   (1980 605)            R180
C77      1 µF/10 µF     E2,5-5            rcl                   (2100 175)            R0
C79      1 µF/10 µF     E2,5-5            rcl                   (1050 175)            R180
C80      1800 pF        C025-025X050      rcl                   (2125.94488 1619.84252) R0
C81      1800 pF        C025-025X050      rcl                   (1745.94488 1619.84252) R0
C82      2200 pF        C025-025X050      rcl                   (2315.94488 1619.84252) R180
C83      2200 pF        C025-025X050      rcl                   (1935.94488 1619.84252) R180
D1       SS26           SMB               diode                 (1070 1605)           R90
D2       LED1           CHIPLED_1206      led                   (226 882)             R90
D3       LED2           CHIPLED_1206      led                   (226.91339 788.54331) R90
F1       Ferrit         SM-1206           inductor-neosid       (600 1150)            R0
J1       MONOSW2        NEUTRIK-NRJ4HF    Audio Jacks 0.25 inch (3150 370.07874)      R90
J2       MONOSW2        NEUTRIK-NRJ4HF    Audio Jacks 0.25 inch (0 470.07874)         R270
JP1                     JP1               jumper                (175 1700)            R90
JP2                     JP2               jumper                (1855 705)            R0
JP3                     JP2               jumper                (1555 705)            R0
JP4                     JP2               jumper                (2235 1505)           R0
JP5                     JP2               jumper                (1935 1505)           R0
JP6                     JP1               jumper                (371.25984 981.49606) R270
L2       4.7-22uH       FPS               my_inductors          (855 1595)            R90
Q1       IRLML6402TRPBF SOT23             IRLML6402             (755.90551 1035.43307) R180
R1       270R           M0805             rcl                   (552 892.84252)       R0
R2       1.8K           M0805             rcl                   (549.55906 777.62992) R180
R3       1K             M0805             rcl                   (889.76378 1035.43307) R270
R4       1K             M0805             rcl                   (838.58268 1173.22835) R180
R5       10K            M0805             rcl                   (1455 975)            R270
R8       1 k            0207/10           rcl                   (1450 175)            R0
R9       10 k           0207/10           rcl                   (1600 300)            R180
R12      1 k            0207/10           rcl                   (1600 475)            R180
R14      10 k           0207/10           rcl                   (1150 387.5)          R180
R20      1K/0.1%        M0805             rcl                   (615 1745)            R0
R21      1K/0.1%        M0805             rcl                   (739.01575 1437.67717) R180
R22      47K/0.1%       M0805             rcl                   (435 1742.5)          R180
R23      18K/0.1%       M0805             rcl                   (435 1655)            R180
SV1                     MA03-2            con-lstb              (1430.62992 1655)     R0
SV2                     MA04-1            con-lstb              (2791.85039 1575.62992) R0
T1       PN2222         TO92              PN2222                (2131.49606 417.12598) R90
U1       PIC16F886-I/SP DIP254P762X508-28 PIC16F886-I_SP        (2855 1260)           R90
U2       FT232RL        SSOP28-LD         FT232RL               (1167.04724 970)      R0
U3       6581           DIL28-6           Mos6581_sid           (2210 1105)           R0
U4       MT3608L        SOT23-6           kwr-master-2016-08    (625 1620)            R180
X1       USB-B-H        USB-B-H           con-usb-2             (300 1307.48031)      R0

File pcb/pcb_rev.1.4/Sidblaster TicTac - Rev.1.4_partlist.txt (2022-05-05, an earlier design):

Partlist

Exported from Sidblaster TicTac - Rev.1.4.sch at 13.04.2022 14:50

EAGLE Version 7.7.0 Copyright (c) 1988-2016 CadSoft

Assembly variant: 

Part     Value          Device            Package           Library               Sheet

C1       10nF           C-EUC0805K        C0805K            rcl                   1
C2       100nF          C-EUC0805K        C0805K            rcl                   1
C3       100nF          C-EUC0805K        C0805K            rcl                   1
C4       100nF          C-EUC0805K        C0805K            rcl                   1
C5       100nF          C-EUC0805K        C0805K            rcl                   1
C6       100nF          C-EUC0805K        C0805K            rcl                   1
C7       100nF          C-EUC0805K        C0805K            rcl                   1
C8       100nF          C-EU025-025X050   C025-025X050      rcl                   1
C9       100nF          C-EU025-025X050   C025-025X050      rcl                   1
C10      22µF           CPOL-EUE2-4       E2-4              rcl                   1
C11      22µF           CPOL-EUE2-4       E2-4              rcl                   1
C12      100nF          C-EUC0805K        C0805K            rcl                   1
C13      4,7µF          CPOL-EUE2-4       E2-4              rcl                   1
C18      1000pF         C-EU025-025X050   C025-025X050      rcl                   1
C20      100nF          C-EUC0805K        C0805K            rcl                   1
C21      100nF          C-EUC0805K        C0805K            rcl                   1
C70      470pF          C-EU025-025X050   C025-025X050      rcl                   1
C71      470pF          C-EU025-025X050   C025-025X050      rcl                   1
C72      22nF           C-EU025-025X050   C025-025X050      rcl                   1
C73      22nF           C-EU025-025X050   C025-025X050      rcl                   1
C77      1µF/10µF       CPOL-EUE2.5-5     E2,5-5            rcl                   1
C79      1 µF/10µF      CPOL-EUE2.5-5     E2,5-5            rcl                   1
C80      1800pF         C-EU025-025X050   C025-025X050      rcl                   1
C81      1800pF         C-EU025-025X050   C025-025X050      rcl                   1
C82      2200pF         C-EU025-025X050   C025-025X050      rcl                   1
C83      2200pF         C-EU025-025X050   C025-025X050      rcl                   1
D1       ss26           SCHOTTKY-DIODESMD SMB               diode                 1
D2       LED1           LEDCHIPLED_1206   CHIPLED_1206      led                   1
D3       LED2           LEDCHIPLED_1206   CHIPLED_1206      led                   1
F1       Ferrit         R-EU_0207/5V      0207/5V           rcl                   1
J1       MONOSW2        MONOSW2           NEUTRIK-NRJ4HF    Audio Jacks 0.25 inch 1
J2       MONOSW2        MONOSW2           NEUTRIK-NRJ4HF    Audio Jacks 0.25 inch 1
JP1      Voltage Select JP1E              JP1               jumper                1
JP2      CAP2           JP2E              JP2               jumper                1
JP3      CAP1           JP2E              JP2               jumper                1
JP4      POTX           JP2E              JP2               jumper                1
JP5      POTY           JP2E              JP2               jumper                1
JP6      Shield2GND     JP1E              JP1               jumper                1
L2       4,7 - 22uH     1212_FPS          FPS               my_inductors          1
Q1       IRLML6402TRPBF IRLML6402TRPBF    SOT23             IRLML6402             1
R1       270R           R-EU_M0805        M0805             rcl                   1
R2       270R           R-EU_M0805        M0805             rcl                   1
R3       1k             R-EU_M0805        M0805             rcl                   1
R4       1k             R-EU_M0805        M0805             rcl                   1
R5       10k            R-EU_M0805        M0805             rcl                   1
R8       1k             R-EU_0207/10      0207/10           rcl                   1
R9       10k            R-EU_0207/10      0207/10           rcl                   1
R12      1k             R-EU_0207/10      0207/10           rcl                   1
R14      10k            R-EU_0207/10      0207/10           rcl                   1
R20      1k             R-EU_M0805        M0805             rcl                   1
R21      1k             R-EU_M0805        M0805             rcl                   1
R22      47k            R-EU_M0805        M0805             rcl                   1
R23      18k            R-EU_M0805        M0805             rcl                   1
SV1      ISP            MA03-2            MA03-2            con-lstb              1
SV2      Paddles        MA04-1            MA04-1            con-lstb              1
T1       PN2222         PN2222            TO92              PN2222                1
U1       PIC16F886-I/SP PIC16F886-I/SP    DIP254P762X508-28 PIC16F886-I_SP        1
U2       FT232RL        FT232RL           SSOP28-LD         FT232RL               1
U3       6581           6581              DIL28-6           Mos6581_sid           1
U4       MT3608         MT3608            SOT23-6           kwr-master-2016-08    1
X1       USB-B-H        USB-B-H           USB-B-H           con-usb-2             1

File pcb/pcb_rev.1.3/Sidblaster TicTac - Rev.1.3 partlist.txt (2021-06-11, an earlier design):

Partlist

Exported from Sidblaster TicTac - Rev.1.3.brd at 05.06.2021 18:59

EAGLE Version 7.7.0 Copyright (c) 1988-2016 CadSoft

Assembly variant: 

Part     Value          Package           Library               Position (mm)         Orientation

C1       10 nF          C0805K            rcl                   (14.097 26.543)       R0
C2       100 nF         C0805K            rcl                   (30.099 30.861)       R180
C3       100 nF         C0805K            rcl                   (25.146 18.542)       R0
C4       100 nF         C0805K            rcl                   (26.035 30.861)       R180
C5       100 nF         C0805K            rcl                   (62.865 37.973)       R0
C6       100 nF         C0805K            rcl                   (35.941 34.798)       R180
C7       100 nF         C0805K            rcl                   (43.114 38.013)       R180
C8       100 nF         C025-025X050      rcl                   (26.67 13.97)         R0
C9       100 nF         C025-025X050      rcl                   (49.53 10.795)        R270
C10      22µF           E2-4              rcl                   (13.589 32.639)       R0
C11      22µF           E2-4              rcl                   (27.94 34.798)        R0
C18      1000 pF        C025-025X050      rcl                   (46.355 4.445)        R180
C20      100n           C0805K            rcl                   (12.5095 38.481)      R270
C21      100n           C0805K            rcl                   (30.353 38.989)       R270
C70      470 pF         C025-025X050      rcl                   (35.56 15.367)        R0
C71      470 pF         C025-025X050      rcl                   (45.339 15.367)       R0
C72      22 nF          C025-025X050      rcl                   (40.386 15.367)       R180
C73      22 nF          C025-025X050      rcl                   (50.292 15.367)       R180
C77      1 µF/10 µF     E2,5-5            rcl                   (53.34 4.445)         R0
C79      1 µF/10 µF     E2,5-5            rcl                   (26.67 4.445)         R180
C80      1800 pF        C025-025X050      rcl                   (53.999 41.144)       R0
C81      1800 pF        C025-025X050      rcl                   (44.347 41.144)       R0
C82      2200 pF        C025-025X050      rcl                   (58.825 41.144)       R180
C83      2200 pF        C025-025X050      rcl                   (49.173 41.144)       R180
D1       ss26           SMB               diode                 (27.178 40.767)       R90
D2       LED1           CHIPLED_1206      led                   (5.7404 22.4028)      R90
D3       LED2           CHIPLED_1206      led                   (5.7636 20.029)       R90
F1                      0207/5V           rcl                   (15.875 29.21)        R0
J1       MONOSW2        NEUTRIK-NRJ4HF    Audio Jacks 0.25 inch (80.01 9.4)           R90
J2       MONOSW2        NEUTRIK-NRJ4HF    Audio Jacks 0.25 inch (0 11.94)             R270
JP1                     JP1               jumper                (4.445 43.18)         R90
JP2                     JP2               jumper                (47.117 17.907)       R0
JP3                     JP2               jumper                (39.497 17.907)       R0
JP4                     JP2               jumper                (56.769 38.227)       R0
JP5                     JP2               jumper                (49.149 38.227)       R0
JP6                     JP1               jumper                (9.43 24.93)          R270
L2       4,7 - 22uH     FPS               my_inductors          (21.717 40.513)       R90
R1       270            M0805             rcl                   (14.0208 22.6782)     R0
R2       270            M0805             rcl                   (13.9588 19.7518)     R180
R8       1 k            0207/10           rcl                   (36.83 4.445)         R0
R9       10 k           0207/10           rcl                   (40.64 7.62)          R180
R12      1 k            0207/10           rcl                   (40.64 12.065)        R180
R14      10 k           0207/10           rcl                   (29.21 9.8425)        R180
R20      1k             M0805             rcl                   (15.621 44.323)       R0
R21      1K             M0805             rcl                   (21.971 34.417)       R180
R22      47K            M0805             rcl                   (11.049 44.2595)      R180
R23      18K            M0805             rcl                   (11.049 42.037)       R180
SV1                     MA03-2            con-lstb              (36.338 42.037)       R0
SV2                     MA04-1            con-lstb              (70.913 40.021)       R0
T1       PN2222         TO92              PN2222                (54.14 10.595)        R90
U1       PIC16F886-I/SP DIP254P762X508-28 PIC16F886-I_SP        (72.517 32.004)       R90
U2       FT232RL        SSOP28-LD         FT232RL               (26.543 24.638)       R0
U3       6581           DIL28-6           Mos6581_sid           (56.134 28.067)       R0
U4       MT3608         SOT23-6           kwr-master-2016-08    (15.875 41.148)       R180
X1       USB-B-H        USB-B-H           con-usb-2             (7.62 33.21)          R0

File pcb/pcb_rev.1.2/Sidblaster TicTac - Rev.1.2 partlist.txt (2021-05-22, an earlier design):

Partlist

Exported from Sidblaster TicTac - Rev.1.2.sch at 02.03.2018 15:00

EAGLE Version 7.7.0 Copyright (c) 1988-2016 CadSoft

Assembly variant: 

Part     Value          Device            Package           Library               Sheet

C1       10 nF          C-EUC0805K        C0805K            rcl                   1
C2       100 nF         C-EUC0805K        C0805K            rcl                   1
C3       100 nF         C-EUC0805K        C0805K            rcl                   1
C4       100 nF         C-EUC0805K        C0805K            rcl                   1
C5       100 nF         C-EUC0805K        C0805K            rcl                   1
C6       100 nF         C-EUC0805K        C0805K            rcl                   1
C7       100 nF         C-EUC0805K        C0805K            rcl                   1
C8       100 nF         C-EU025-025X050   C025-025X050      rcl                   1
C9       100 nF         C-EU025-025X050   C025-025X050      rcl                   1
C10      22µF           CPOL-EUE2-4       E2-4              rcl                   1
C11      22µF           CPOL-EUE2-4       E2-4              rcl                   1
C18      1000 pF        C-EU025-025X050   C025-025X050      rcl                   1
C20      100n           C-EUC0805K        C0805K            rcl                   1
C21      100n           C-EUC0805K        C0805K            rcl                   1
C70      470 pF         C-EU025-025X050   C025-025X050      rcl                   1
C71      470 pF         C-EU025-025X050   C025-025X050      rcl                   1
C72      22 nF          C-EU025-025X050   C025-025X050      rcl                   1
C73      22 nF          C-EU025-025X050   C025-025X050      rcl                   1
C77      1 µF/10 µF     CPOL-EUE5-5       E5-5              rcl                   1
C79      1 µF/10 µF     CPOL-EUE5-5       E5-5              rcl                   1
C80      1800 pF        C-EU025-025X050   C025-025X050      rcl                   1
C81      1800 pF        C-EU025-025X050   C025-025X050      rcl                   1
C82      2200 pF        C-EU025-025X050   C025-025X050      rcl                   1
C83      2200 pF        C-EU025-025X050   C025-025X050      rcl                   1
D1       ss26           SCHOTTKY-DIODESMD SMB               diode                 1
D2       LED1           LEDCHIPLED_1206   CHIPLED_1206      led                   1
D3       LED2           LEDCHIPLED_1206   CHIPLED_1206      led                   1
F1                      R-EU_0207/5V      0207/5V           rcl                   1
J1       MONOSW2        MONOSW2           NEUTRIK-NRJ4HF    Audio Jacks 0.25 inch 1
J2       MONOSW2        MONOSW2           NEUTRIK-NRJ4HF    Audio Jacks 0.25 inch 1
JP1                     JP1E              JP1               jumper                1
JP2                     JP2E              JP2               jumper                1
JP3                     JP2E              JP2               jumper                1
JP4                     JP2E              JP2               jumper                1
JP5                     JP2E              JP2               jumper                1
JP6                     JP1E              JP1               jumper                1
L2       4,7 - 22uH     1212_FPS          FPS               my_inductors          1
R1       270            R-EU_M0805        M0805             rcl                   1
R2       270            R-EU_M0805        M0805             rcl                   1
R8       1 k            R-EU_0207/10      0207/10           rcl                   1
R9       10 k           R-EU_0207/10      0207/10           rcl                   1
R12      1 k            R-EU_0207/10      0207/10           rcl                   1
R14      10 k           R-EU_0207/10      0207/10           rcl                   1
R20      1k             R-EU_M0805        M0805             rcl                   1
R21      1K             R-EU_M0805        M0805             rcl                   1
R22      47K            R-EU_M0805        M0805             rcl                   1
R23      18K            R-EU_M0805        M0805             rcl                   1
SV1                     MA03-2            MA03-2            con-lstb              1
SV2                     MA04-1            MA04-1            con-lstb              1
T1       BC237          BC237             TO92              transistor            1
U1       PIC16F886-I/SP PIC16F886-I/SP    DIP254P762X508-28 PIC16F886-I_SP        1
U2       FT232RL        FT232RL           SSOP28-LD         FT232RL               1
U3       6581           6581              DIL28-6           Mos6581_sid           1
U4       MT3608         MT3608            SOT23-6           kwr-master-2016-08    1
X1       USB-B-H        USB-B-H           USB-B-H           con-usb-2             1

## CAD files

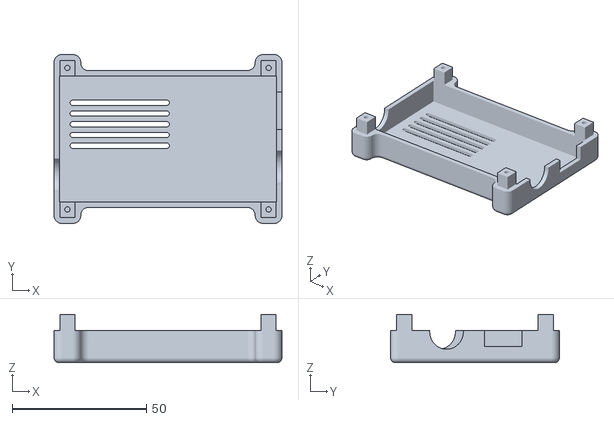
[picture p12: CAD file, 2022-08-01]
3d_printed_case/SIDBlaster-USB-Tic-Tac-Case-Top-No-Text-V1.stl
85.0 x 63.0 x 18.0

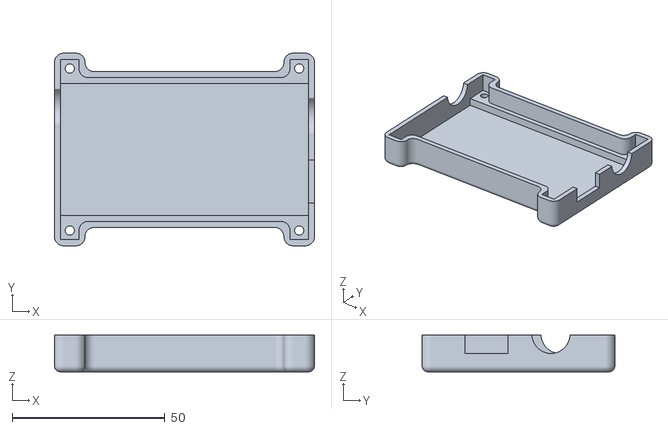
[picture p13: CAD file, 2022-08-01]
3d_printed_case/SIDBlaster-USB-Tic-Tac-Case-Bottom-V1.stl
85.0 x 63.0 x 12.0

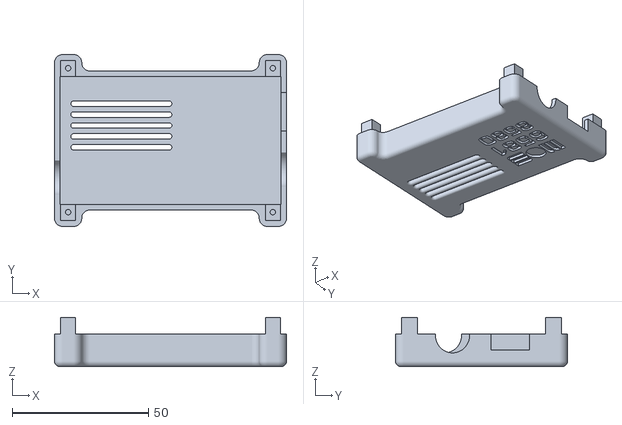
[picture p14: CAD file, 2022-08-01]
3d_printed_case/SIDBlaster-USB-Tic-Tac-Case-Top-V1.stl
85.0 x 63.0 x 18.0

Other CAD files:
3d_printed_case/SIDBlaster-USB-Tic-Tac-Case-Bottom-V1.blend
3d_printed_case/SIDBlaster-USB-Tic-Tac-Case-Top-No-Text-V1.blend
3d_printed_case/SIDBlaster-USB-Tic-Tac-Case-Top-V1.blend

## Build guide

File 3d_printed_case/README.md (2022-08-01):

3D-printed case for SIDBlaster-USB Tic-Tac Edition by tyristori.

Two different versions of top part included. With and without the text.

Use 3 x 12 screws.

<br />This work is licensed under a <a rel="license" href="http://creativecommons.org/licenses/by/4.0/">Creative Commons Attribution 4.0 International License</a>.

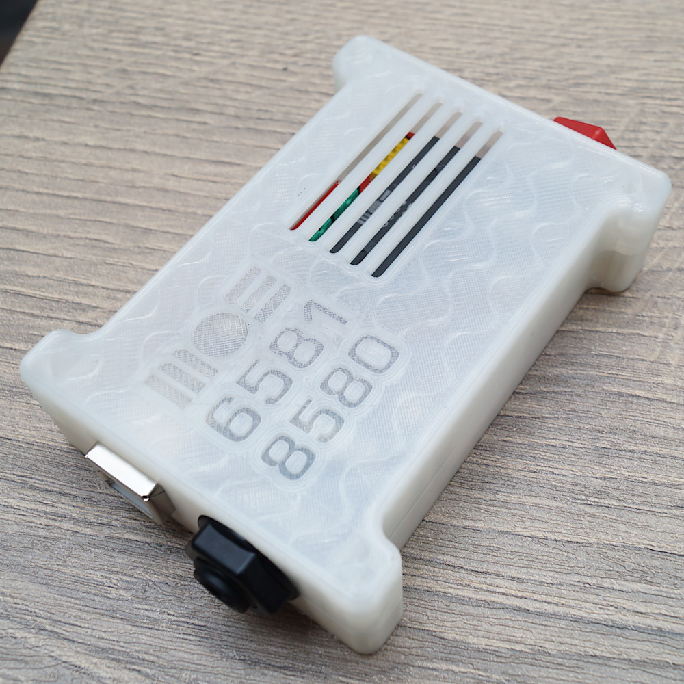
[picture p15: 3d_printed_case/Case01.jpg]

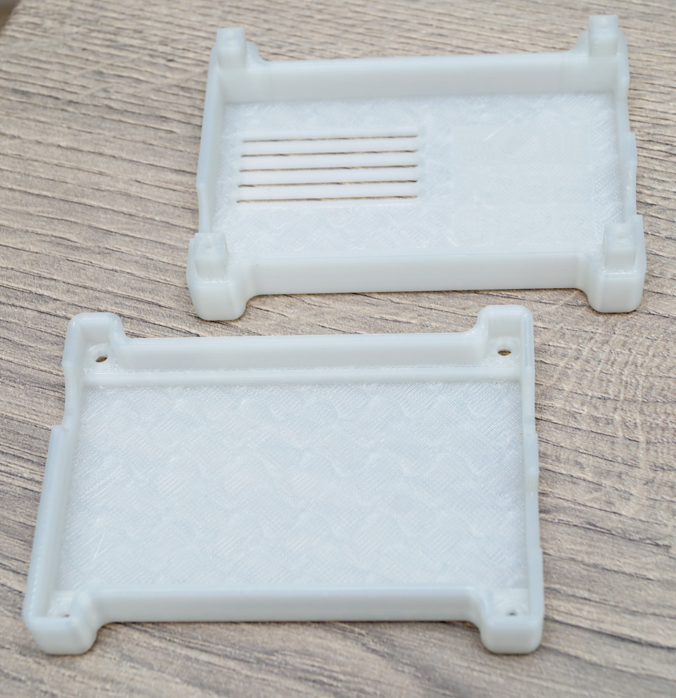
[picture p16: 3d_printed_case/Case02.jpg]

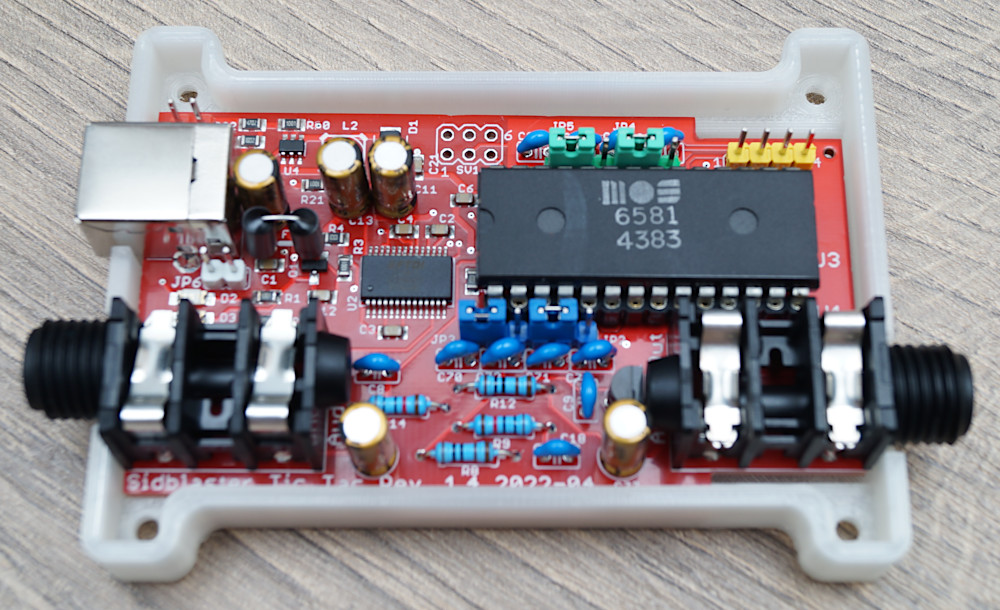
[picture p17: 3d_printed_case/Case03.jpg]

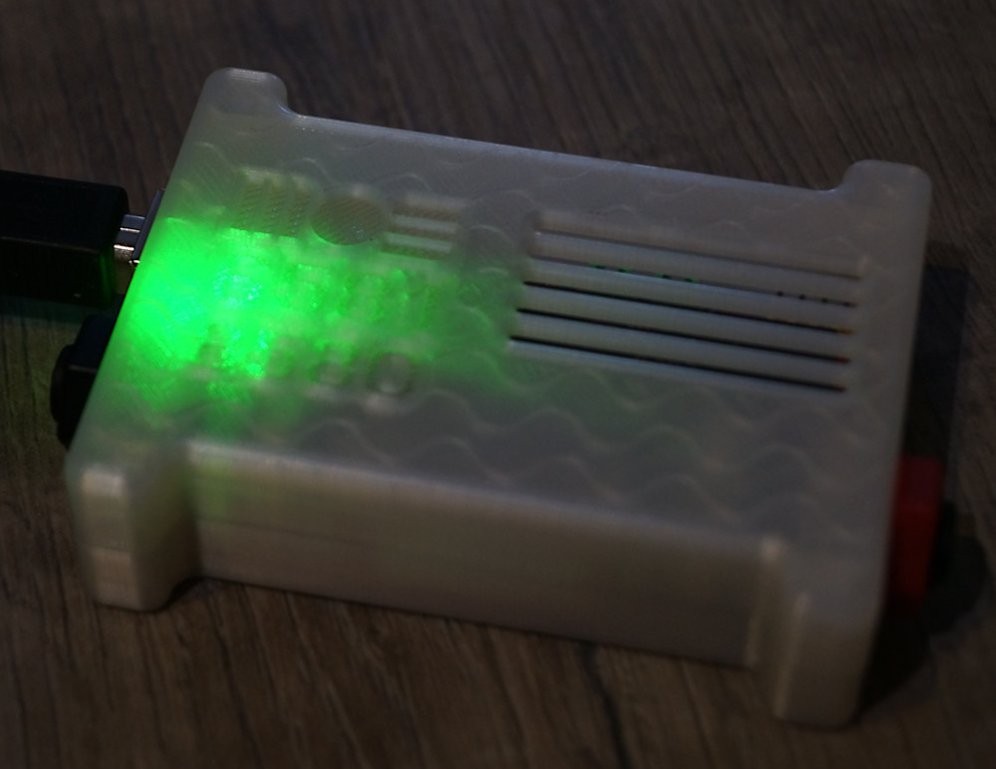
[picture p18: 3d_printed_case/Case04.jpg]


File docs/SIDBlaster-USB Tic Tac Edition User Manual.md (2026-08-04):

SIDBlaster-USB Tic Tac Edition

# SIDBLASTER-USB — TIC TAC EDITION

*– A real SID Chip on PC or Mac*

## USER MANUAL

by Andreas Schumm, Rev. 1.4

Copyright© 2024 [www.crazy-midi.de](http://www.crazy-midi.de/) – License: [CC BY-ND 4.0](https://creativecommons.org/licenses/by-nd/4.0/deed.en)

---

# 1. Introduction

The SIDBlaster-USB Tic Tac comprises premium "open-source" hardware for using a genuine "SID"-sound chip for C64 emulation, playback of SID tunes and music production as a little box on the USB port of a personal computer or Mac.

SIDBlaster-USB Tic Tac is based upon "SIDBlaster-USB", and is 100% compatible with it.

## 1.1 Improvements

- Good value universal current supply 9V or 12V
- Original C64-audio wiring
- Optional connection facility for two Paddles
- Switchable filter capacitors
- Switchable capacitors for Paddle
- Precisely fitting printed circuit board for assembly into a Tic Tac candy box
- Audio-In
- Professional 6,3mm mono audio jack sockets
- Cozy blue power LED
- (Rev.1.2:) red TX/RX-LED
- (Rev. 1.2 white jumper to connect GND and shield (experimental)
- prepared for read access (firmware 1.1)

# 2. General information

- Plug and play is not possible, the SIDBlaster must be plugged in before using in an application. Also, do not unplug the SIDBlaster before you have finished the application.
- When you are not using the SIDBlaster it is recommended to unplug the USB-connection since this prolongs the life of the SID-chip.
- Since a SID-chip produces heat, use a heat-sink on the chip if possible and make sure there is sufficient ventilation (leave the flap of the Tic Tac candy box open).

# 3. Hardware installation

## 3.1 SID-chip installation

SID-Chip Installation

*A SIDBlaster-USB with correctly installed 8580*

Always use ESD protection (e.g. an anti-static bracelet) to avoid damaging the SID-chip and other electrical components when installing it in the SIDBlaster.

To remove a SID chip, for example, use a screwdriver, lever it out alternately, be careful not to damage the circuit board or components. Before inserting a SID, bend the legs straight with a pair of pliers, press carefully, check that none of the legs bend over.

## 3.2 Jumper settings

Jumper overview

### 3.2.1 For the 6581 SID-chip:

- JP1: must be open (12V).
- JP2-JP5: Place all jumpers on the left side (pins 1-2).

### 3.2.2 For the 8580 SID-chip:

- JP1: must be closed (9V).
- JP2-JP5: Place all jumpers on the right side (pins 2-3).

## 3.3 Other jumpers on the hardware

### 3.3.1 JP6 (White)

From Rev. 1.2 and on. Experimental, connects USB shield to ground; you may try it to counteract interfering noise.

### 3.3.2 SV2:Paddle connector (yellow)

Here you have access to the two A/D converters of the SID chip. For example, you can connect 2 rotary potentiometers as paddles. This is of interest for programmers. You can also use the function with the SID object for Max/MSP.

| Pin | Function |
|---|---|
| 1 | +5V |
| 2 | POTX |
| 3 | POTY |
| 4 | GND |

Paddle connector diagram

### 3.3.3 SV1: ISP Connector

Use a Picit 3 programmer to flash the microcontroller. MPLAB IPE is used as software.

| Pin | Function |
|---|---|
| 1 | MCLR/VPP |
| 2 | +5V |
| 3 | GND |
| 4 | PGD (ICSPDAT) |
| 5 | PGC (ICSPCLK) |
| 6 | n.c. |

SV1 ISP Connector wiring

## 3.4 USB and audio connections

### 3.4.1 USB jack

Connect the SIDBlaster hardware to a USB port using a type A-B USB cable of good quality. It can also work with a good quality USB-hub.

### 3.4.2 Audio-out jack

The audio output is designed as a professional 1/4" jack socket. Connect the audio output of the SIDBlaster to your mixer or audio interface using an unbalanced (mono) cable.

### 3.4.3 Audio-in jack

The second audio jack on the SIDBlaster is an audio input and is also an unbalanced connection. If you are unsure which connector is which, the connectors are marked on the PCB. Be careful about what you connect to the input of the SID-chip. These chips are old and very sensitive to electrical spikes and too high voltages.

## 3.5 exSIDBlaster (optional firmware hack)

If you want, you can convert your SIDBlaster into part of an exSID with a small hardware modification and new firmware – a project by Thibaut Varène with especially mature, cycle-accurate firmware. After the conversion you effectively have an exSID with one SID chip, usable e.g. with JSIDPlay2 (enable "Fake Stereo" there).

This is an experimental modification at your own risk – neither Andreas Schumm nor Thibaut Varène take any responsibility for it. Details on the exact procedure (cutting PIC pin 7, soldering a bridge from PIC pin 15 to SID socket pin 5, flashing new firmware) can be found in the exSIDBlaster folder of the SIDBlaster-USB-Tic-Tac-Edition repository.

# 4. Software

## 4.1 The FTDI D2XX driver

### 4.1.1 Windows

The SIDBlaster needs to do a digital "handshake" the first time it is connected via USB. This requires an internet connection. The handshake will not work if your internet connection is set to "Metered Connection" in Windows. To solve this, temporarily disable "Metered Connection", wait a moment for the SIDBlaster to do the handshake, and then re-enable "Metered Connection".

The latest Windows versions provide the FTDI driver via the update function. So check: Settings / Updates / Optional Updates.

The SIDBlaster is recognized by Windows as a "USB Serial Converter". It may be recognized as a COMx device with ports (in Device Manager). Edit: Your SIDBlaster have to be flashed correctly with the FTDI prog tool and the template from the SIDBlaster project in this case. The actual hardsid.dll doesn't accept incorrectly flashed SIDBlasters.

With older versions of Windows, installation of a driver by FTDI may be necessary, available at: <http://www.ftdichip.com/Drivers/D2XX.htm>

### 4.1.2 Linux

Download D2XX driver from: <https://ftdichip.com/drivers/d2xx-drivers/>

Please install FTDI drivers explained in chapter '2 Installing the D2XX driver' from here: <https://www.ftdichip.com/Support/Documents/AppNotes/AN_220_FTDI_Drivers_Installation_Guide_for_Linux.pdf>

If device still cannot be used, please install a workaround mentioned in chapter '1.1 Overview':

```
$ sudo vi /etc/udev/rules.d/91-sidblaster.rules

ACTION=="add", ATTRS{idVendor}=="0403", ATTRS{idProduct}=="6001", MODE="0666", RUN+="/bin/sh -c 'rmmod ftdi_sio && rmmod usbserial'"

$ sudo udevadm control --reload-rules && udevadm trigger
```

### 4.1.3 MacOS

Note: it may be necessary to switch off the security monitoring in MacOS or to authorize all developers.

```
sudo spctl --master-disable
```

Could also work:
```
sudo xattr -rd com.apple.quarantine / Your software path.app
```

Download and install D2XX Driver from: <https://ftdichip.com/drivers/d2xx-drivers/>

use the instructions from: <https://ftdichip.com/wp-content/uploads/2020/08/AN_134_FTDI_Drivers_Installation_Guide_for_MAC_OSX-1.pdf>

Download and install D2XXHelper from the same site.

## 4.2 The hardsid library

Is the "driver" resp. "middleware" of the SIDBlaster, so to say. Under windows it comprises a reprogrammed DLL of the Hardsid, thus, software programmed for the Hardsid becomes compatible for the SIDBlaster. Later the DLL was ported to linux and macos. The DLL is made and maintained by Stein Pedersen. Linux/Mac port was made by Ken Händel.

### 4.2.1 Windows

- Download from: <https://crazy-midi.de/joomla/index.php/mydownloads>
- Recommended: install the driver via its own installer (installs the DLL system-wide to Windows\System32). Alternatively, you can manually copy the right hardsid.dll into the program directory of a single program.
- The 64 bit version is required by the 64 bit version of vice and also by the 64 bit versions of AIASS.

### 4.2.2 Linux

- Download from: <https://crazy-midi.de/joomla/index.php/mydownloads>
- copy libhardsid.so to /usr/local/lib/
- apply chmod 0755 on libhardsid.so
- copy hardsid.hpp to /usr/local/include/

### 4.2.3 MacOS

- Download from: <https://crazy-midi.de/joomla/index.php/mydownloads>
- copy libhardsid.dylib to /usr/local/lib/
- copy hardsid.hpp to /usr/local/include/

### 4.2.4 SIDBLASTERUSB_WRITEBUFFER

Depending on your system, tunes with high data rates (multi speed tunes or digitunes) may play slower if the latency of the USB driver is too high. This can be remedied by setting the driver write buffer size to a larger value, for instance. Even down to 0, works on fast machines.

#### 4.2.4.1 Windows
```
set SIDBLASTERUSB_WRITEBUFFER_SIZE=8
```

#### 4.2.4.2 Linux/MacOS
```
export SIDBLASTERUSB_WRITEBUFFER_SIZE=8
```

## 4.2.5 The SIDBlasterTool

With SIDBlasterTool you can check if library and device communication works.

You can also set the SID type and change the serial number. The type is saved as part of the device description and evaluated by applications such as JSIDPlay.

The SIDBlasterTool is part of the driver package: <https://crazy-midi.de/joomla/index.php/mydownloads>

## 4.2.6 Notes for developers

For developers who want to write applications using the hardsid library, I refer to hardsid.hpp as well as integrators_guide.md (included with the driver installer). The driver's source code is here: <https://github.com/gh0stless/SIDBlasterUSB_HardSID-emulation-driver>. You can find a few more tips in the AIASS-VST repository in the doc folder. Do not forget to call the destructor method manually when exiting under MacOS and Linux.

Detailed instructions on how to create the hardsid library can be found here (thanks to Ken Handel): <https://haendel.ddns.net/~ken/sidblaster.html>

## 4.3 Applications

### 4.3.1 Vice64

The famous C64 emulator supports up to 3 SIDBlasters. In the simplest case, you now have a C64 with original sound. But you can also use the SIDBlaster with Vice64 as a MIDI expander, by activating the MIDI emulation, and load a synthesizer program like Station64. Windows only.

### 4.3.2 ACID64 Player

Best SIDBlaster support, if you have several devices you can even play stereo and 3SID tunes (Only Windows). Version 4.3 supports the SIDBlaster again. From this version on, ACID64 talks to the SIDBlaster directly – the hardsid library is no longer required.

### 4.3.3 SidPlay2

Good SID player, suitable as a jukebox because of playlists. Windows only.

### 4.3.4 GoatTracker

Tracker. Supports one or two SIDBlasters, Windows only.

### 4.3.5 JSIDPlay2

JSIDPlay2 is a fantastic C64 content media player. In the current version it has the best SIDBlaster support. It may not be as handy as ACID64, but once you have familiarized yourself with it, it is a very powerful and comprehensive program. Available for Windows, MacOS and Linux.

JSIDPlay2 supports the SIDBlaster natively, only Java is required. You don't need to install any D2XX drivers or the hardsid library.

#### 4.3.5.1 JSIDPlay2 Android app

Get this app to turn your phone into a mobile SIDPlayer. Connect your SIDBlaster to your mobile phone. You will need an OTG USB adapter and probably a mono to stereo adapter for the headphones.

### 4.3.6 CloanTo's C64 Forever

Just copy the hardsid.dll in the directory of Vice (Help/About/VICE Plugin, Open File Location). Then, enter "-sidenginemodel hardsid" in the "Custom parameters" field (in Tools/Options/Emulation, under Plugins/VICE/Custom parameters...)

### 4.3.7 AIASS

AIASS Is A SID Synthesizer

#### 4.3.7.1 sid-object for Max/MSP & Max4Live

Is a Max/MSP C-external for the SIDBlaster-USB.

#### 4.3.7.2 AIASS – Max4Live device(s)

The AIASS for MAX4LIVE project is a set of max4live devices to control one or more SIDBlaster-USB as a synthesizer application. This makes it possible to produce music with an original SID chip MOS 6581 or MOS 8580 from the Commodore 64, in a modern DAW.

#### 4.3.7.3 AIASS – VST

AIASS as VST (on all systems)

### 4.3.8 ASID Protocol player

Small program that can be used to play ASID MIDI data streams on the SIDBlaster. Supports up to 3 SIDBlasters for 2SID and 3SID tunes. This allows you to use the payer from the website DeepSID, for example.

# 5. Multiple device operation

You can use multiple SIDBlaster-USB at the same time.

ACID Player, JSIDPlay2, Vice, Goattracker and AIASS support this.

The benefit lies in the playback of stereo or 3Sid tunes, fake stereo, automatic selection of the correct SID type with JSIPlay2 (set type with the SIDBlastertool), or several instruments with AIASS (not yet VST).

# 6. Links

- <http://crazy-midi.de/>
- <https://github.com/gh0stless/SIDBlaster-USB-Tic-Tac-Edition>
- <https://github.com/gh0stless/SIDBlasterTool>
- <https://github.com/gh0stless/SIDBlaster-ASID-Player>
- <https://github.com/gh0stless/AIASS-for-MAX4LIVE>
- <https://github.com/gh0stless/AIASS-Uno-VST>
- <https://github.com/gh0stless/SIDBlasterUSB_HardSID-emulation-driver>
- <https://vice-emu.sourceforge.io/>
- <https://www.acid64.com>
- <http://www.gsldata.se/c64/spw/> (SIDPlay2)
- <https://haendel.ddns.net/~ken/> (JSIDPlay2)
- <https://sourceforge.net/projects/goattracker2/>
- <https://www.facebook.com/groups/2305052182957954/>

# 7. Thanks to

- Davey (The Phantom) for creating the original SIDBlaster.
- Stein Pedersen for assistance and the sidblaster.dll.
- Wilfred Bos for his ACID Player and tips and helping.
- Ken Händel for the POSIX port and his work on the library
- Karl-Werner Riedel for his help with designing the Tic Tac hardware.
- Magnus Hansson for writing some original parts of this manual.
- A special thanks to Thibaut VARÈNE for his exSID and his great firmware, which can also be used with the SIDBlaster with a hack.
- Borjana Konstantinowa for her patience with me.

Coswig, Saxony 04/08/26

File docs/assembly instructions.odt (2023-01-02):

Assembly instructions SIDBlaster-USB Tic Tac

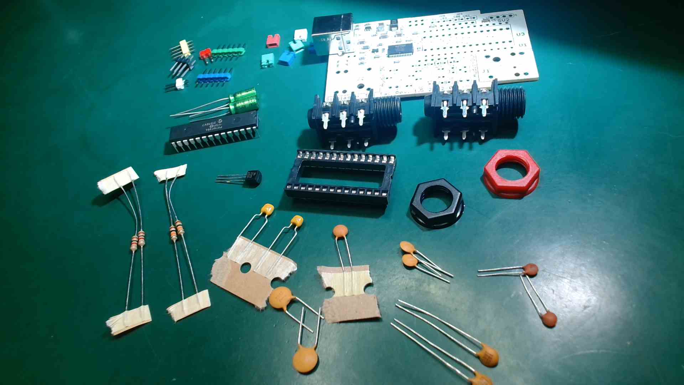
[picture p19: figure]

For the assembly, some experience in soldering is required. Under all circumstances, you’ll likely need:

- soldering station with a normal and a pointed soldering tip
- solder wire 0.7 and 1mm
- working lamp with magnifier
- flux pen
- hand suction pump
- tweezers
- small side cutter
- small flat or needle nose pliers
- isopropyl alcohol or denatured alcohol
- brush or toothbrush
- meter
- wooden toothpick
- Access to a Windows PC for the FTDI software to flashthe USB chip

Preparation:

Download the whole GitHub repository binary. (Clone it or download it as a zip file)

Assembly Steps:

Owners of a kit with a pre-assembled SMD part (Rev. 1.4) start at point 16.

Owners of a kit with a pre-assembled SMD part (Rev. 1.5) start at point 18.

1. equip FT232 chip (U2); the following pin numbers must be soldered up: 1; 4; 5; 7; 12; 14; 15; 16; 17; 18; 20; 21; 23; 25. hint: subsequently check the right connections according to the circuit diagram with a multimeter ("wiring test") Please note: For correct operation, pin 26 must be switched on mass. This was forgotten in the layout of revision 1.2. Therefore, bridge pin 25 with pin 26. This is fixed from revision 1.3
2. equip LEDs D2: blue; D3: red; consider mark!
3. equip R1 and R2, 270 Ohms
4. equip C1, 10nFs
5. equip U4, Imprint: B6287G; attention! U4 is turned by 180° in relation to U2
6. equip C3, C4, C2, C21, C5, C6, C7, C20, C12(from Rev. 1.4): 100nFs
7. equip R23 (18k)
8. equip R22 (47k)
9. equip R20 und R21 (1k)
10. solder on inductor (L2), tip: tin-plate pads in advance
11. solder diode D1 (SS26)
12. Q1 (from Rev. 1.4) equip
13. Equip R3, R4 (from Rev. 1.4) 1K
14. Equip R5 (from Rev. 1.4) 10K
15. clean circuit-board
16. equip L1
17. C10, C11 (22uFs), C13 (4,7µF)(from Rev 1.4) consider polarity
18. equip USB jack socket

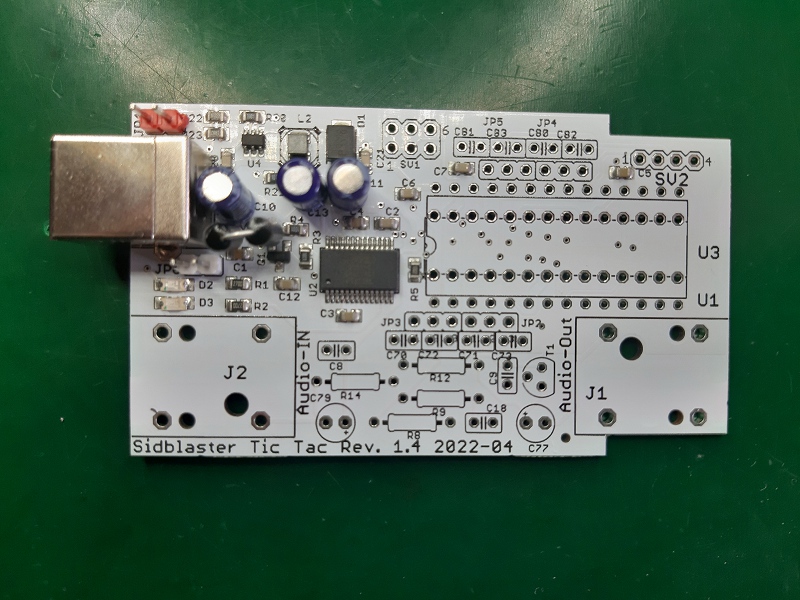
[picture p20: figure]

19. test: connect current source, blue LED must be on; measure voltage between pin 14 (GND) and pin 28 (+12V) of U3 (SID)

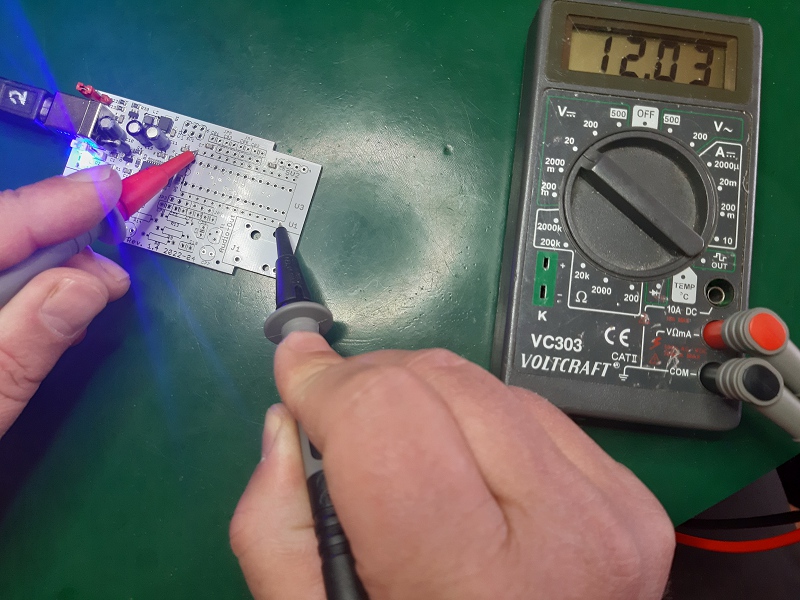
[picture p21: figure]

20. equip JP1 (red) and JP6 (white)
21. Test: set JP1 and mesure voltage at the SID socket (must be 9V now)


22. solder on U1, pinch off spare ends
23. IC socket for SID: cut connections with side cutter, sand smooth

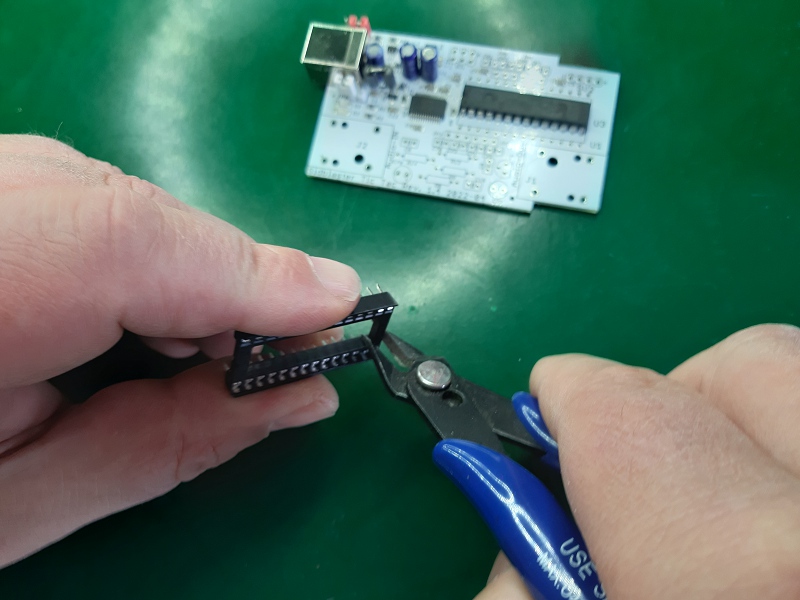
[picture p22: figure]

24. solder in the two parts of the socket

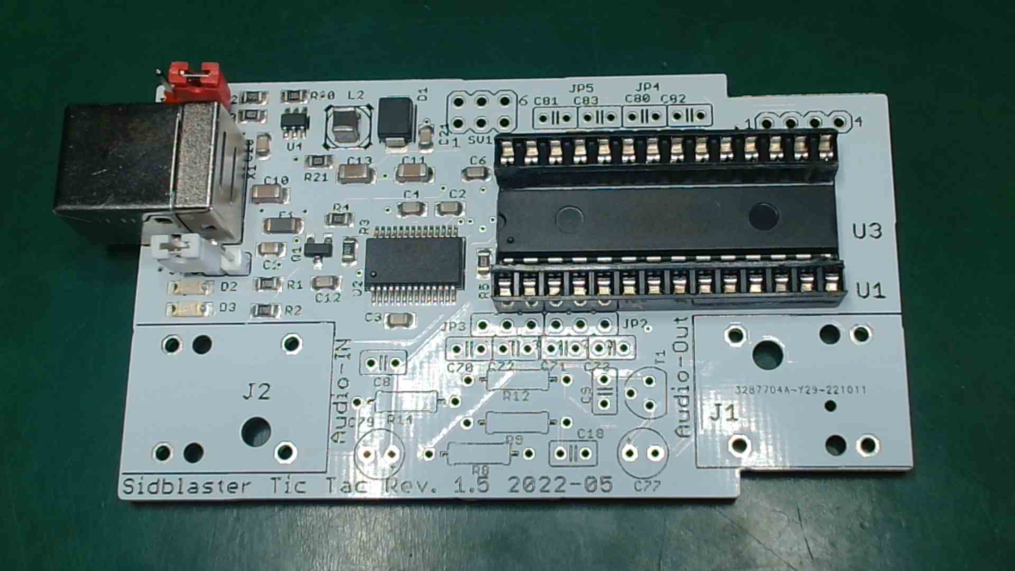
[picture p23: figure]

25. flash FT232 template: software tool "FT_Prog" by FTDI required. Connect circuit board, start FT Prog, scan for device, load template (GitHub), right click on Device ->Apply Template. Then click "program" and program. Attantion! New template for Rev. 1.4!


26. equip SV1

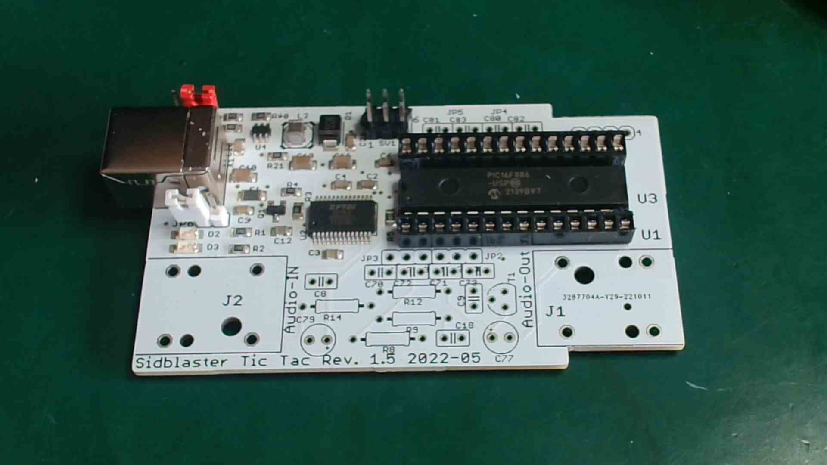
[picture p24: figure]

27. flash PIC µC: A programming device like PicIt 3 is needed, possibly build adapter cable (see manual), software: MPLAB IPE. Kit customers receive a pre-programmed PIC.

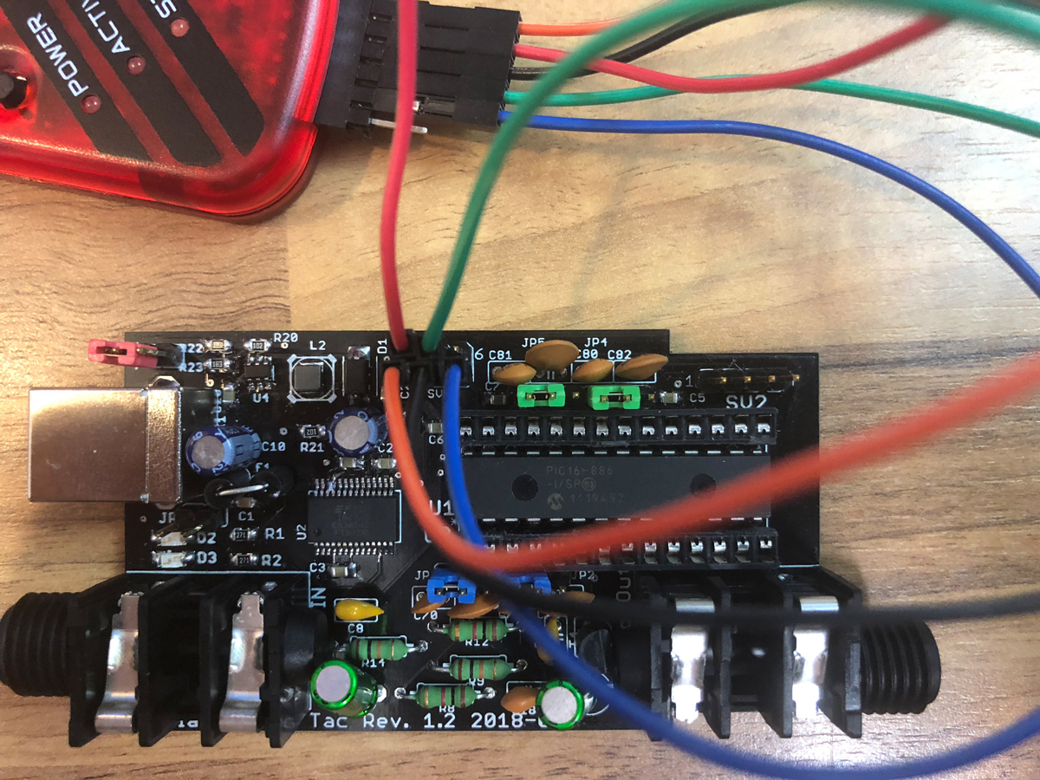
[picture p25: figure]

28. Test: Connect board and start ACID 64 Player (Version 3.6.3; copy hardsid.dll (32Bit (In folder hardsid_library in GitHub Repository)) to same folder before), play tune, SIDBlaster should be recognized, and red (green) LED flicker.

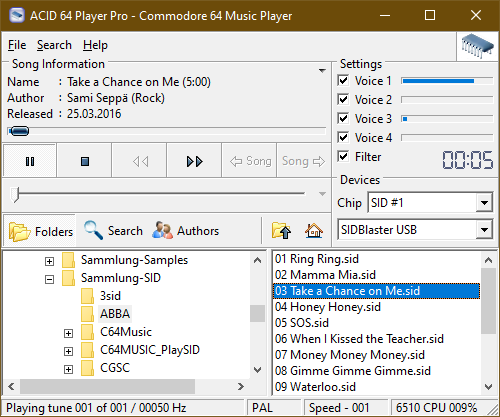
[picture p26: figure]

  1. Note: It is best to equip 2 groups per blue (JP2&3) and green (JP4&5) pin strip with the associated capacitors and solder them together, otherwise holes could become clogged. If the holes get blocked, use a suction pump and toothpick. 2. Note: It is best to always solder strips and components to one pin first, so you have the convenient opportunity to correct the fit again.
29. equip JP2 & JP3 (blue); JP4 & JP5 (green)
30. equip SV2 (yellow)

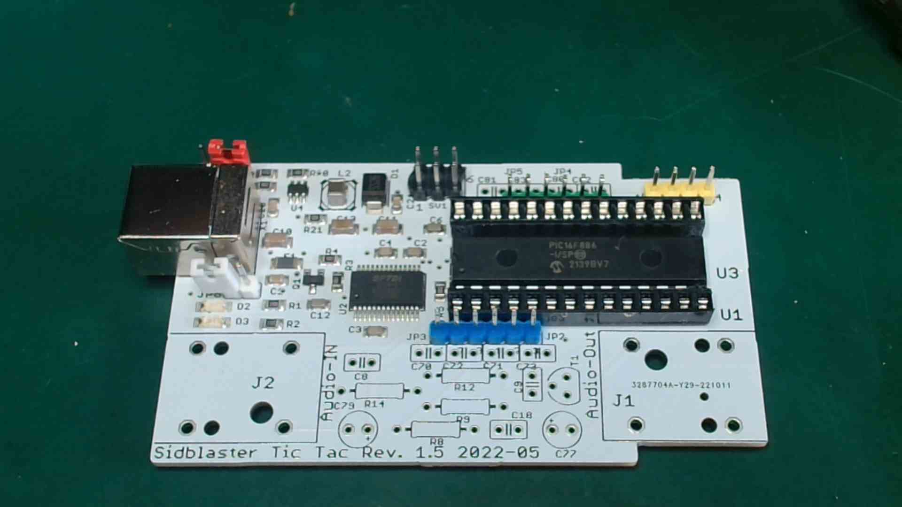
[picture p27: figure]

31. equip C70, C71 (470pFs)(471)
32. equip C72, C73 (22nFs) (223)
33. equip C80, C81 (1800pFs)(182)
34. equip C82, C83 (2,2nFs)(222)

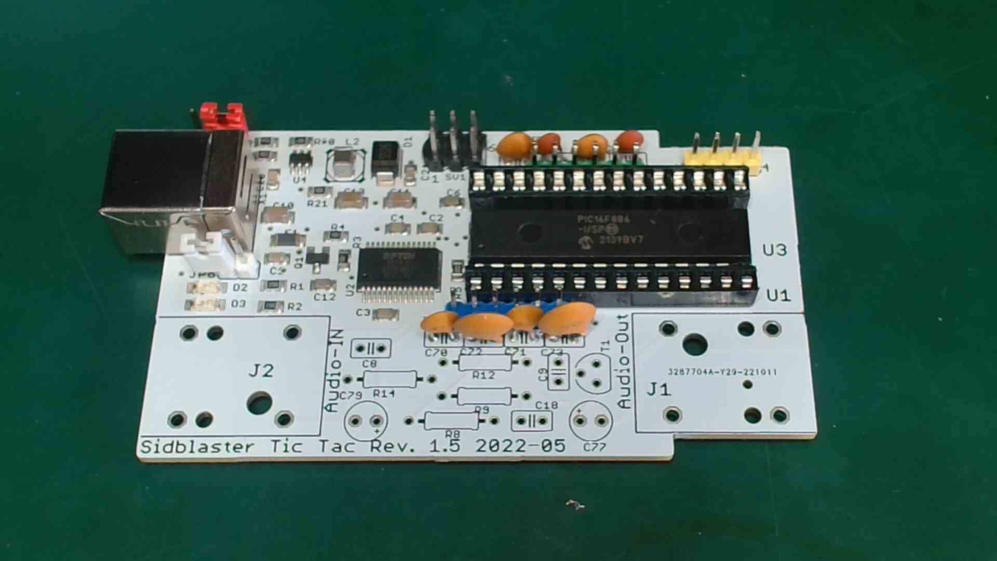
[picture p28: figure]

35. equip R12, R8 (1K)(brown/black/red)
36. equip R14, R9 (10K)(brown/black/orange)

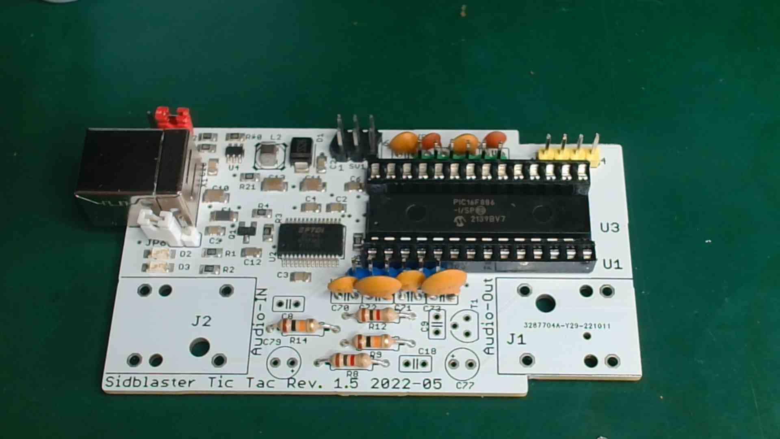
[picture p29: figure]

37. equip C18 (1000pFs)(102)
38. equip C8, C9 (100nFs)(104)

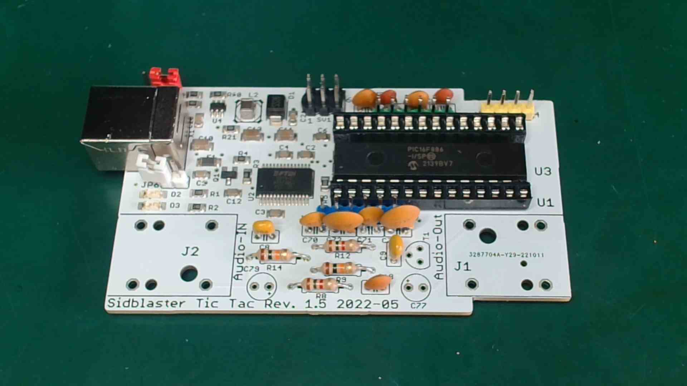
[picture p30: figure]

39. equip T1, observe polarity according to data sheet! (May deviate from the equipment label!) With Rev.1.2 a PN2222A must be fitted the wrong way round, from Rev.1.3 the equipment label is right for PN2222A

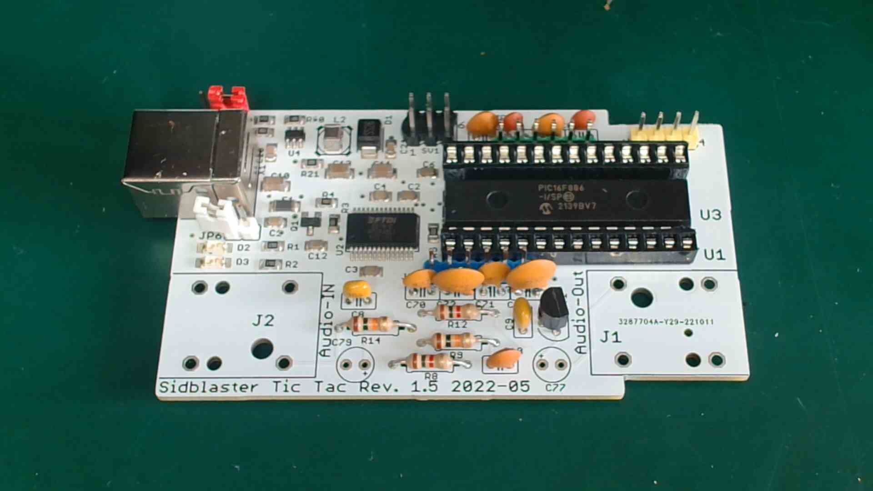
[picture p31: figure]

40. equip C77, C79 (10uFs, bipolar), polarity irrelevant
41. solder on jack sockets
42. set jumper JP1: red; JP4 & JP5: green; JP2 & JP3: blue; JP6: white

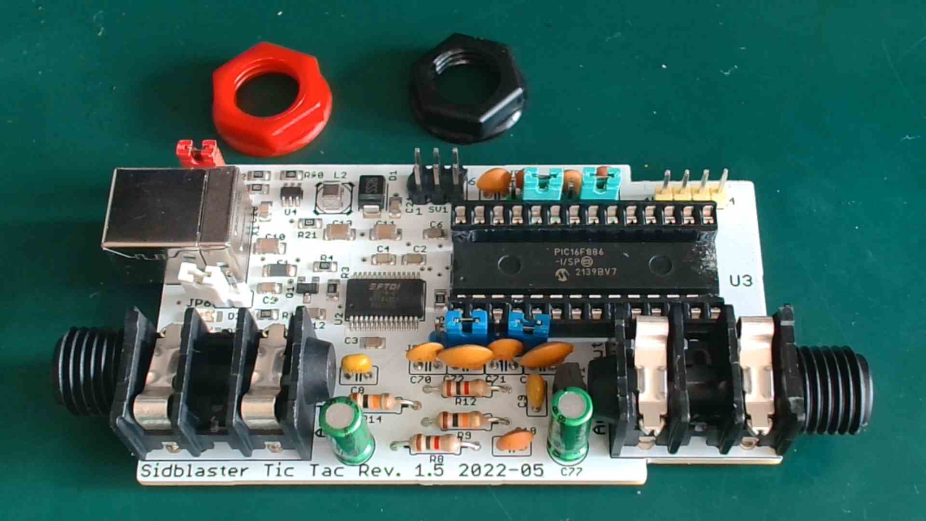
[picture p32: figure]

43. clean the circuit board with a toothbrush and spirit and let it dry. I personally get the best results with denatured alcohol.
44. measure voltages again
45. install SID
46. check jumper (see manual)
47. connect to personal computer and test with ACID player (Version 3.6.3 with hardsid.dll, see above).

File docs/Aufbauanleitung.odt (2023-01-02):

Aufbauanleitung SIDBlaster-USB Tic Tac


Zum Aufbau ist etwas Löterfahrung nötig. Unbedingt brauchen sie wahrscheinlich:

- Lötstation mit einer normalen und einer spitzen Lötspitze
- Lötdraht 0,7 und 1mm
- Lupen-Arbeitsleuchte
- Flussmittelstift
- Handabsaugpumpe
- Pinzette(n)
- kleinen Seitenschneider
- kleine Flach- oder Spitzzange
- Isopropylalkohol oder Spiritus
- Pinsel oder Zahnbürste
- Messgerät (Multimeter)
- Holz-Zahnstocher
- Zugriff auf einen Windows PC für die FTDI Software zum flashen des USB-Chips

Vorbereitung:

Laden Sie das ganze GitHub Repository binär herunter. (Clonen Sie es oder laden Sie es als Zip Datei)

Einzelne Arbeitsschritte:

Besitzer eines Bausatzes mit vorbestücktem SMD-Teil (Rev. 1.4) beginnen bei Punkt 16.

Besitzer eines Bausatzes mit vorbestücktem SMD-Teil (Rev. 1.5) beginnen bei Punkt 18.

1. FT232 Chip bestücken (U2) folgende Pins MÜSSEN verlötet sein: 1; 4; 5; 7; 12; 14; 15; 16; 17; 18; 20; 21; 23; 25. Tipp: Im Anschluss mit einem Multimessgerät die richtigen Verbindungen laut Schaltplan prüfen ("durchklingeln"). Hinweis: Pin 26 (Test) soll für korrekten Betrieb auf Masse geschalten werden. Das wurde im Layout der Revision 1.2 vergessen. Brücken Sie deshalb Pin 25 mit Pin 26. Ab Rev. 1.3 ist das gefixt.
2. LEDs bestücken: D2: Blau; D3: Rot; Markierung beachten!
3. R1 und R2 bestücken, 270 Ohm
4. C1 bestücken, 10nF
5. U4 bestücken Aufdruck: B6287G Achtung! U4 liegt um 180° gedreht zu U2
6. C3, C4, C2, C21, C5, C6, C7, C20 (C12 ab. Rev. 1.4) bestücken, 100nF
7. R23 (18k) bestücken
8. R22 (47k) bestücken
9. R20 und R21 (1k) bestücken
10. Spule (L2) auflöten, Tipp: Pads vorher verzinnen
11. Diode D1 (SS26) verlöten
12. Q1 (ab. Rev. 1.4) bestücken
13. R3, R4 (ab. Rev. 1.4) 1K bestücken
14. R5 (ab. Rev. 1.4) 10K bestücken
15. Platine säubern

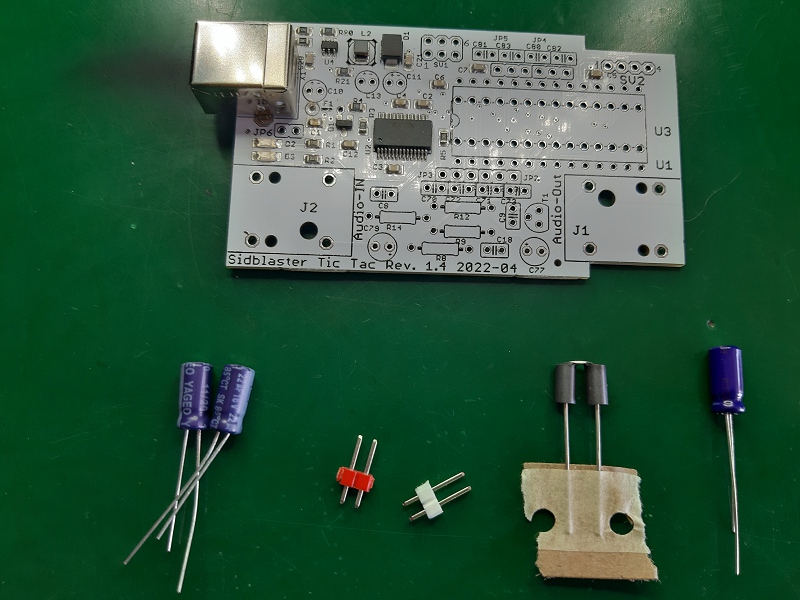
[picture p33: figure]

16. L1 bestücken
17. C10, C11 (22uF), C13 (4,7µF)(ab Rev. 1.4) Polung beachten, bestücken
18. USB-Buchse bestücken


19. Test: Stromquelle anschließen, blaue LED muss leuchten; Spannung messen zwischen Pin 14 (GND) und Pin 28 (+12V) von U3 (SID)


20. JP1 (rot) und ; JP6 (Weiß) bestücken
21. Test: JP1 setzen und noch mal Spannung am SID-Sockel messen (muss jetzt 9V sein)


22. U1 auflöten, überschüssige Enden ab-zwacken
23. IC-Sockel für SID: Mit Seitenschneider die Verbindungsstege raus-knipsen, verschleifen


24. Die zwei Teile des Sockels einlöten


25. FT232 Template programmieren: Man braucht das Softwaretool "FT_PROG" von FTDI. Platine anschließen, FT_PROG starten, nach Device scannen, Template laden (GitHub), Rechtsklick auf Device ->“apply template“. Danach "program" klicken und programmieren. Achtung! Für Rev. 1.4 neues Template!


26. SV1 bestücken


27. PIC µC programmieren: Ein Programmiergerät wie PicIt 3 wird benötigt, evtl. Programmierkabel anfertigen, (siehe User Manual) Software: MPLAB IPE. Bausatzkunden bekommen ein vorprogrammierten PIC geliefert!


28. Test: Platine anschließen und ACID 64 Player (Version 3.6.3; hardsid.dll (32Bit (Im Ordner hardsid_library im GitHub Repository)) in selben Ordner vorher kopieren) starten, Tune abspielen, SIDBlaster sollte erkannt werden, und rote (grüne) LED flackern.


  1. Hinweis: Am besten in 2 Gruppen je Stiftleiste blau(JP2&3) und grün (JP4&5) mit zugehörigen Kondensatoren bestücken und zusammen verlöten, da sich sonst Löcher zusetzen könnten. Setzen sich trotzdem Löcher zu, Absaugpumpe und Zahnstocher verwenden.
  2. Hinweis: Leisten, Bauteile am besten immer erst an einem Pin verlöten, so hat man die bequeme Möglichkeit den Sitz noch einmal zu korrigieren.
29. JP2 & JP3 (Blau); JP4 & JP5 (Grün) bestücken
30. (optional) SV2 (Gelb) bestücken


31. C70, C71 (470pF)(471) bestücken
32. C72, C73 (22nF)(223) bestücken
33. C80, C81 (1800pF)(182) bestücken
34. C82, C83 (2,2nF)(222) bestücken


35. R12, R8 (1K)(Braun/Schwarz/Rot) bestücken
36. R14, R9 (10K)(Braun/Schwarz/Orange) bestücken


37. C18 (1000pF)(102) bestücken
38. C8, C9 (100nF)(104) bestücken


39. T1 bestücken, Polung laut Datenblatt beachten! (Kann von Bestückungsaufdruck abweichen!) Bei Rev.1.2 muss ein PN2222A verkehrt herum bestückt werden, ab Rev.1.3 ist der Bestückungsaufdruck richtig für PN2222A


40. C77, C79 (10uF, bipolar) bestücken, Polung egal
41. Klinkenbuchsen auflöten
42. Jumper setzen JP1: Rot; JP4 & JP5: Grün; JP2 & JP3: Blau; JP6: Weiß


43. Platine mit Zahnbürste und Spiritus reinigen, trocknen lassen. Mit Spiritus erziele ich persönlich die besten Ergebnisse.
44. Noch einmal Spannungen messen
45. SID montieren
46. Jumper überprüfen (siehe Handbuch)
47. An PC anschließen und mit ACID-Player (Version 3.6.3 mit hardsid.dll (siehe oben) testen.

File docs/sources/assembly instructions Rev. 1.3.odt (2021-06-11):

Assembly instructions SIDBlaster-USB Tic Tac

For the assembly, some experience in soldering is required. Under all circumstances, you’ll likely need:

- soldering station with a normal and a pointed soldering tip
- working lamp with magnifier
- flux pen
- tweezers
- small side cutter
- isopropyl alcohol
- brush
- meter
- wooden toothpick

Assembly Steps:

1. equip FT232 chip (U2); the following pin numbers must be soldered up: 1; 4; 5; 7; 12; 15; 16; 17; 18; 20; 21; 23; 25. hint: subsequently check the right connections according to the circuit diagram with a multimeter ("wiring test") Please note: For correct operation, pin 26 must be switched on mass. This was forgotten in the layout of revision 1.2. Therefore, bridge pin 25 with pin 26. This is fixed from revision 1.3
2. equip LEDs D2: blue; D3: red; consider mark!
3. equip R1 and R2, 270 Ohms
4. equip C1, 10nFs
5. equip U4, Imprint: B6287G; attention! U4 is turned by 180° in relation to U2
6. equip C3, C4, C2, C21, C5, C6, C7, C20: 100nFs
7. equip R23 (18k)
8. equip R22 (47k)
9. equip R20 und R21 (1k)
10. solder on inductor (L2), tip: tin-plate pads in advance
11. solder diode D1 (SS26)
12. clean circuit-board
13. solder on U1, pinch off spare ends
14. equip USB jack socket
15. C10, C11 (22uFs), consider polarity
16. equip L1
17. test: connect current source, blue LED must be on; measure voltage between pin 14 (GND) and pin 28 (+12V) of U3 (SID)
18. IC socket for SID: cut connections with side cutter, sand smooth
19. solder in the two parts of the socket
20. equip JP1-JP6
21. equip SV1 and SV2
22. Test: set JP1 and mesure voltage at the SID socket (must be 9V now)
23. flash FT232 template: software tool "FT_Prog" by FTDI required. Connect circuit board, start FT Prog, scan for device, load template (GitHub), right click on Device ->Apply Template. Then click "program" and program.
24. flash PIC µC: A programming device like PicIt 3 is needed, possibly build adapter cable, software: MPLAB IPE.
25. Test: connect circuit board and start ACIDPlayer, play Tune, Sidblaster should be recognized and red LED should be on
26. equip C70, C71 (470pFs)
27. equip C72, C73 (22nFs)
28. equip C80, C81 (1800pFs)
29. equip C82, C83 (2,2nFs)
30. equip R12, R8 (1K)
31. equip R14, R9 (10K)
32. equip C18 (1000pFs)
33. equip C8, C9 (100nFs)
34. set jumper JP1: red; JP4 & JP5: green; JP2 & JP3: blue; JP6: white
35. Equip T1, observe polarity according to data sheet! (May deviate from the equipment label!) With Rev.1.2 a PN2222A must be fitted the wrong way round, from Rev.1.3 the equipment label is ricky for PN2222A
36. equip C77, C79 (10uFs, bipolar), polarity irrelevant
37. solder on jack sockets
38. measure voltage again
39. install SID
40. check jumper
41. connect to personal computer and test with ACID player.
42. The answer to all questions

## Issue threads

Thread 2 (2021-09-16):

windows drivers

djcyberdad, 2021-09-16:
Has ANYONE gotten Windows to install the driver for this???

I'm about to pull my hair out!!!

gh0stless, 2021-09-16:
What do you mean? The FTDI driver or the hardsid.dll? On latest Win 10 the ftdi driver comes maybe with windows update, check that.

gh0stless, 2021-09-16:
If the hardsid.dll is the issue, remember only the 64bit Version of Vice and the 64 Bit Version of AIASS needs the 64 Bit Version of the DLL. All other programs the 32 Bit version.

djcyberdad, 2021-09-16:
Yes, I am trying to install the x86 version, but I cannot impliment it with regsvr32, nor windows update. It just shows it as an "unknown device"
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

djcyberdad, 2021-09-16:
I cannot find it in the VICE options Drop downs as well

djcyberdad, 2021-09-16:
I'll have to try again later today. but it's the hardsid.dll I think?

On Thu, Sep 16, 2021 at 5:37 AM Andreas Schumm ***@***.***>
wrote:

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

djcyberdad, 2021-09-16:
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

gh0stless, 2021-09-16:
Click on update Driver or check prefernce/update/optional updates

djcyberdad, 2021-09-16:
it does not work when I do that, even when I tell it to look in the folders

gh0stless, 2021-09-16:
Install "by hand": https://ftdichip.com/drivers/d2xx-drivers/

djcyberdad, 2021-09-16:
wait, you meant in "Windows Updates"...theres an Ftdi update

djcyberdad, 2021-09-16:
I thought that was for flashing the PIC

gh0stless, 2021-09-16:
MS changed driver delivery a while ago. It was the same for me with a print driver where I didn't know.

djcyberdad, 2021-09-16:
it is displaying as a serial converter I think...I should take the sid out for this next step if it's what I think it is...

gh0stless, 2021-09-16:
serial converter is rigth

gh0stless, 2021-09-16:
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

djcyberdad, 2021-09-16:
ok, so according to the manual I need to flash my device?

djcyberdad, 2021-09-16:
wait I read that wrong

djcyberdad, 2021-09-16:
Mine does not look like that whatsoever

djcyberdad, 2021-09-16:
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

djcyberdad, 2021-09-16:
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

djcyberdad, 2021-09-16:
im exhausted and my head hurts, I'll try again tomorrow

gh0stless, 2021-09-16:
I just looked at it, (3.5) either it is no longer supported, or only via a commando line parameter. I will test this. I only use versions from 2.4 to 3.2 and they all work fine.

gh0stless, 2021-09-16:
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

OK 3.5 works to, just copy dll to bin folder

djcyberdad, 2021-09-16:
Supurb. I'm in bed now, will check later

On Thu, Sep 16, 2021, 6:22 AM Andreas Schumm ***@***.***>
wrote:

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

djcyberdad, 2021-09-17:
hardsid.dll is in the same folder as x64sc.exe, and hardsid is not showing up in the SID portion of the AUDIO options menu

djcyberdad, 2021-09-17:
did you tweak file at all? Should I use the Hardsid.dll from the github?

gh0stless, 2021-09-17:
https://github.com/gh0stless/SIDBlaster-USB-Tic-Tac-Edition/tree/master/hardsid_library

v.515 should do the job.

djcyberdad, 2021-09-17:
the option is still not there

djcyberdad, 2021-09-17:
ok, I think I got it in VICE 3.2

djcyberdad, 2021-09-17:
do you have a "sidplayer" you can recommend for basic testing?

gh0stless, 2021-09-17:
I always recommend ACID64 Player for a first, quick test. But version 3.6.3! 4.0 no longer supports the hardsid things.

gh0stless, 2021-09-17:
On the other hand, you should check the communication with the SIDBlastertool.exe. If the SIDBlaster tool can access the SIDBlaster, the other programs should also be able to do so.

djcyberdad, 2021-09-17:
I am going to continue to communicate with you via the "info@crazymidi" email, is that okay?

gh0stless, 2021-09-17:
OK

djcyberdad, 2021-09-17:
WE HAVE LIFT OFF

gh0stless, 2021-09-17:
Note on the new driver provision from Microsoft will be added in the manual.

Closed 2021-09-17.

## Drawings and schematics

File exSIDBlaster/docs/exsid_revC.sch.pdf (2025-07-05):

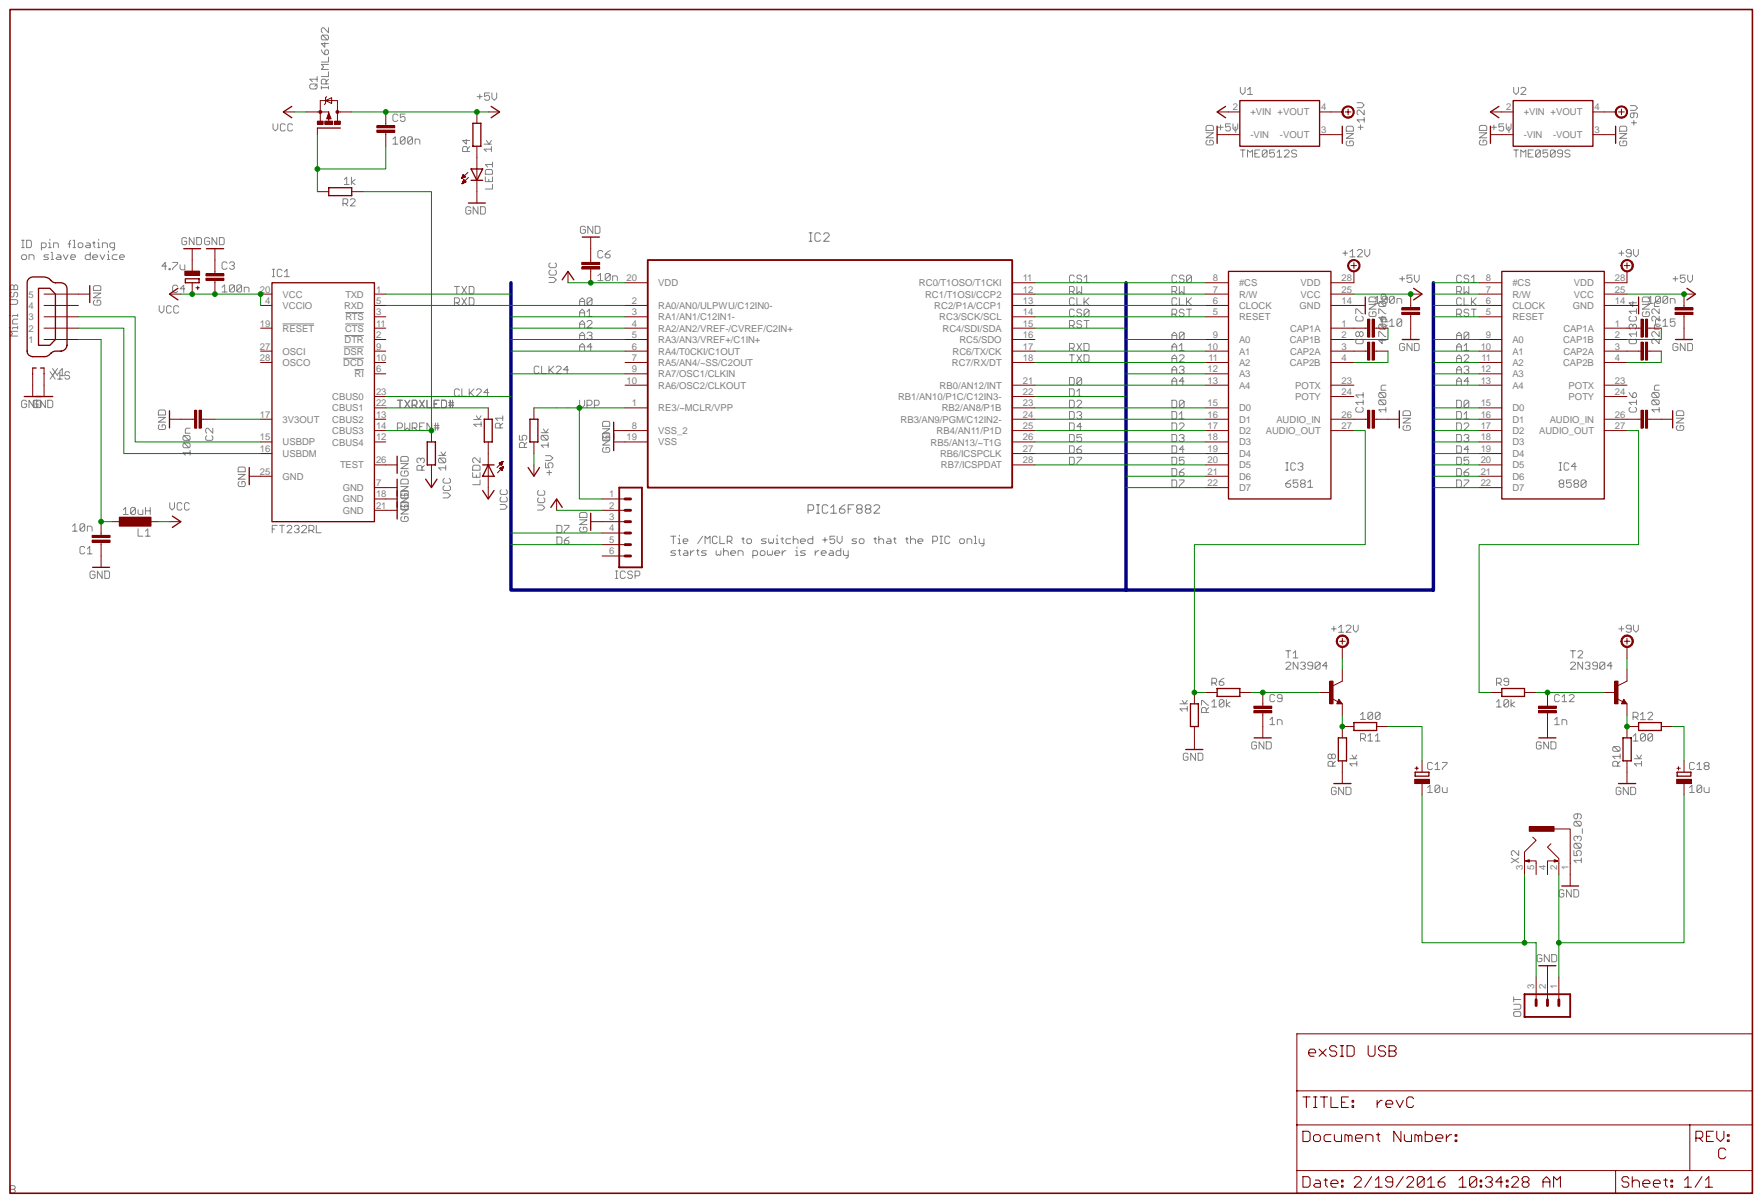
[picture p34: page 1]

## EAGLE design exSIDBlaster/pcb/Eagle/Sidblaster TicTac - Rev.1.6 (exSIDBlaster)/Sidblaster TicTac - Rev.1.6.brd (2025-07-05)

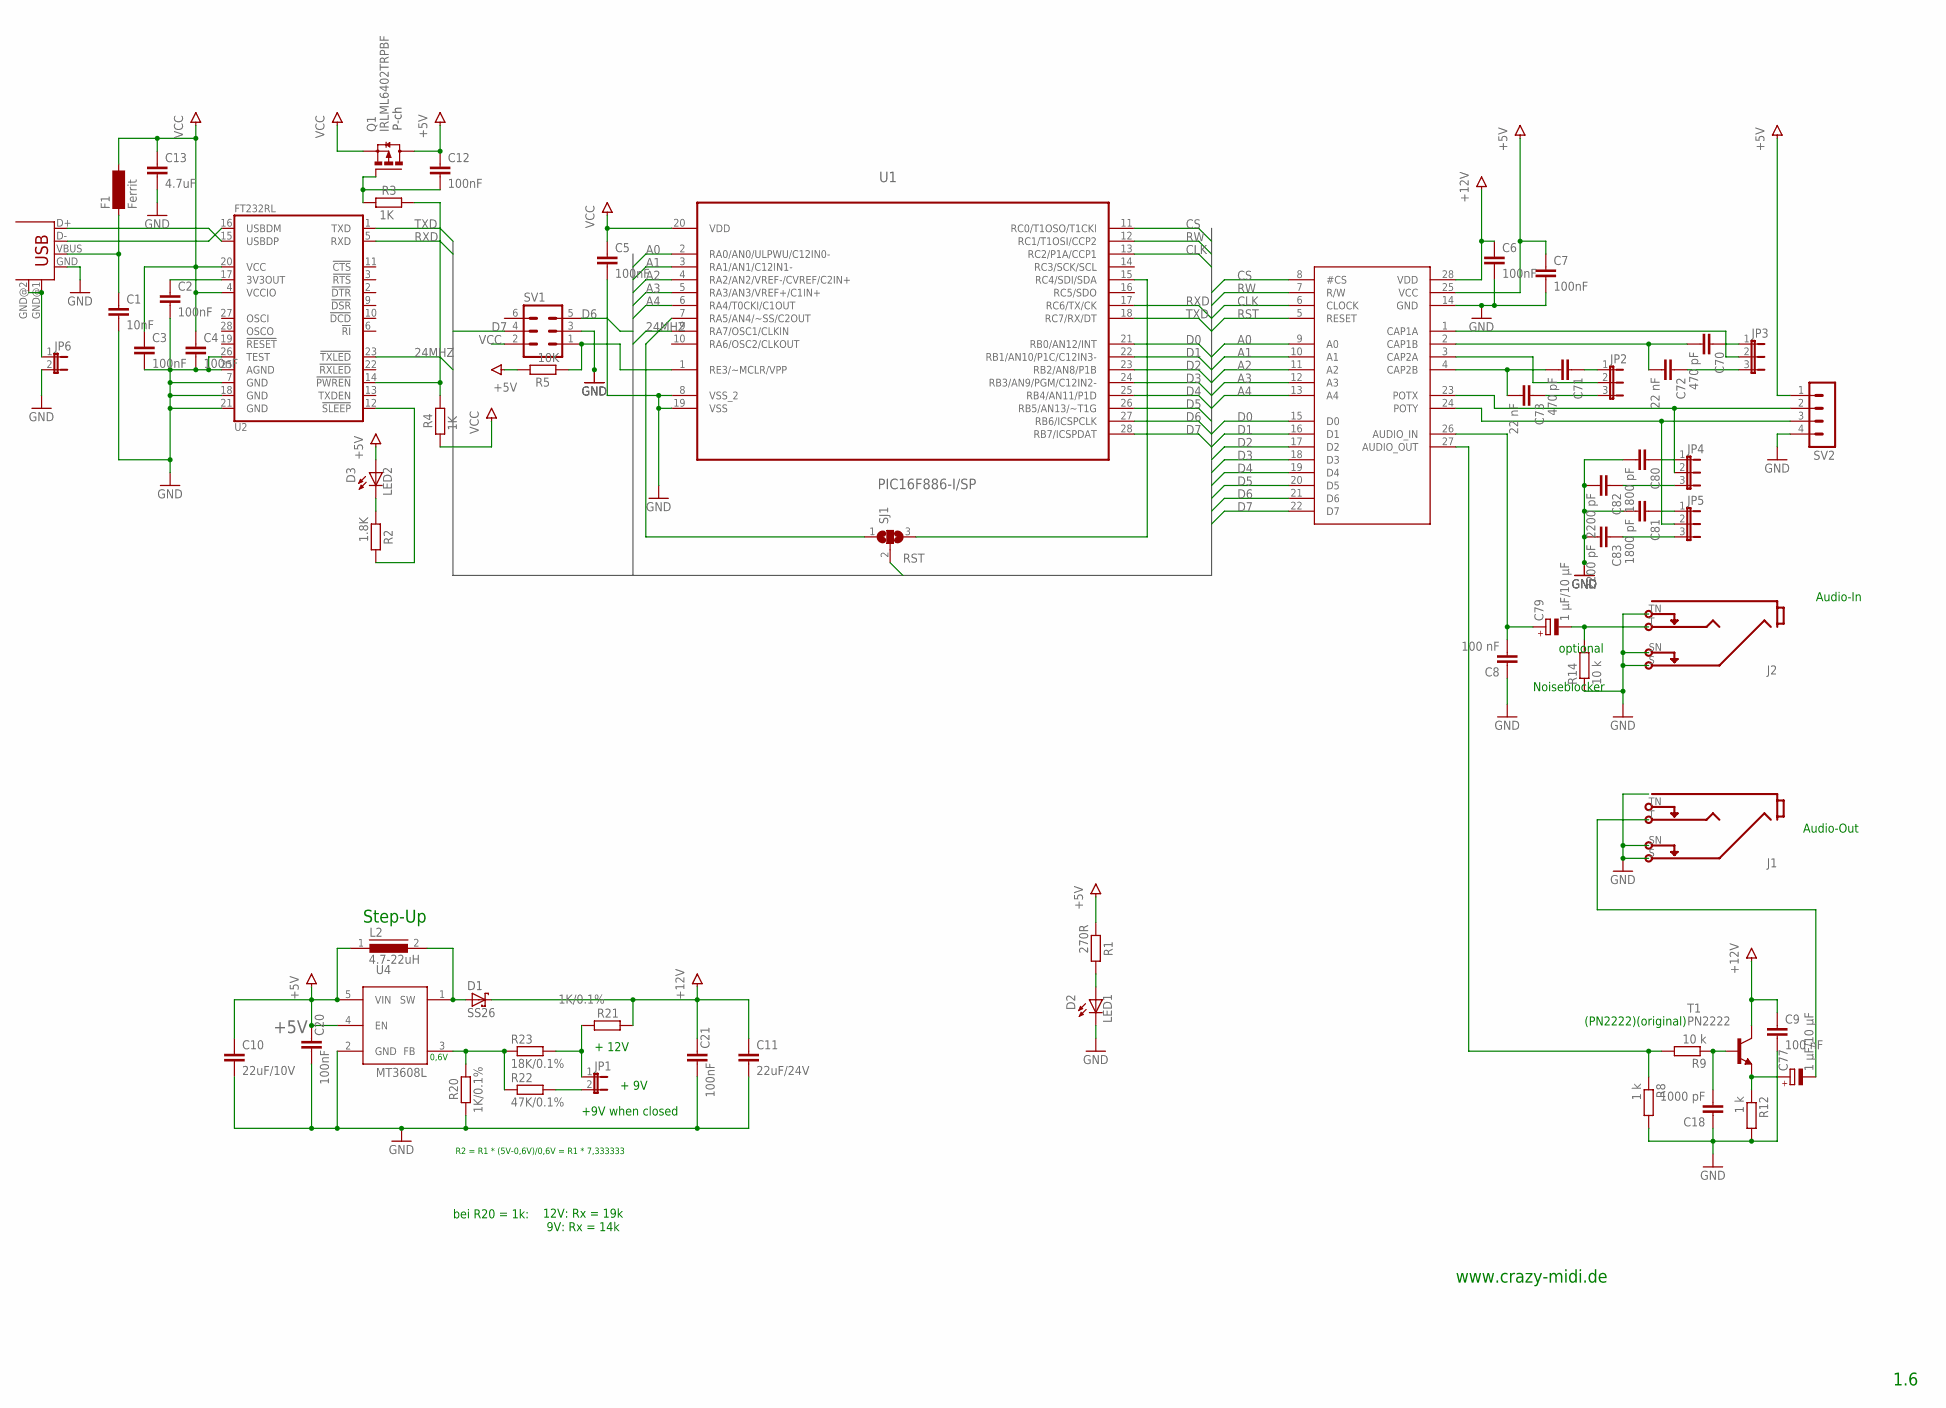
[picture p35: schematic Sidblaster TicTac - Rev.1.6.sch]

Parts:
C1: 10nF; C0805K
C2, C3, C4, C5, C6, C7, C12, C20, C21: 100nF; C0805K
C8, C9: 100 nF; C025-025X050
C10: 22uF/10V; C1206
C11: 22uF/24V; C1206
C13: 4.7uF; C1206
C18: 1000 pF; C025-025X050
C70, C71: 470 pF; C025-025X050
C72, C73: 22 nF; C025-025X050
C77, C79: 1 µF/10 µF; E2,5-5
C80, C81: 1800 pF; C025-025X050
C82, C83: 2200 pF; C025-025X050
D1: SS26; SMB
D2: LED1; CHIPLED_1206
D3: LED2; CHIPLED_1206
F1: Ferrit; SM-1206
J1, J2: MONOSW2; NEUTRIK-NRJ4HF
JP1, JP6: JP1E; JP1
JP2, JP3, JP4, JP5: JP2E; JP2
L2: 4.7-22uH; FPS
Q1: IRLML6402TRPBF; SOT23
R1: 270R; M0805
R2: 1.8K; M0805
R3, R4: 1K; M0805
R5: 10K; M0805
R8, R12: 1 k; 0207/10
R9, R14: 10 k; 0207/10
R20, R21: 1K/0.1%; M0805
R22: 47K/0.1%; M0805
R23: 18K/0.1%; M0805
SJ1: SJ2W; SJ_2
SV1: MA03-2
SV2: MA04-1
T1: PN2222; TO92
U1: PIC16F886-I/SP; DIP254P762X508-28
U2: FT232RL; SSOP28-LD
U3: 6581; DIL28-6
U4: MT3608L; SOT23-6
X1: USB-B-H

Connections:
24MHZ: U1.9 (RA7/OSC1/CLKIN), U2.23 (!TXLED)
+5V: C7.1, C10.1, C12.1, C20.2, D3.A, L2.1, Q1.3 (D), R1.2, R5.1, SV2.1, U3.25 (VCC), U4.4 (EN), U4.5 (VIN)
+12V: C6.1, C9.1, C11.1, C21.2, D1.C, R21.1, T1.3 (C), U3.28 (VDD)
A0: U1.2 (RA0/AN0/ULPWU/C12IN0-), U3.9 (A0)
A1: U1.3 (RA1/AN1/C12IN1-), U3.10 (A1)
A2: U1.4 (RA2/AN2/VREF-/CVREF/C2IN+), U3.11 (A2)
A3: U1.5 (RA3/AN3/VREF+/C1IN+), U3.12 (A3)
A4: U1.6 (RA4/T0CKI/C1OUT), U3.13 (A4)
C1: C2.1, U2.17 (3V3OUT)
CLK: U1.13 (RC2/P1A/CCP1), U3.6 (CLOCK)
CS: U1.11 (RC0/T1OSO/T1CKI), U3.8 (#CS)
D0: U1.21 (RB0/AN12/INT), U3.15 (D0)
D1: U1.22 (RB1/AN10/P1C/C12IN3-), U3.16 (D1)
D2: U1.23 (RB2/AN8/P1B), U3.17 (D2)
D3: U1.24 (RB3/AN9/PGM/C12IN2-), U3.18 (D3)
D4: U1.25 (RB4/AN11/P1D), U3.19 (D4)
D5: U1.26 (RB5/AN13/~T1G), U3.20 (D5)
D6: SV1.5, U1.27 (RB6/ICSPCLK), U3.21 (D6)
D7: SV1.4, U1.28 (RB7/ICSPDAT), U3.22 (D7)
GND: C1.2, C2.2, C3.2, C4.2, C5.2, C6.2, C7.2, C8.1, C9.2, C10.2, C11.2, C13.2, C18.1, C20.1, C21.1, C80.2, C81.2, C82.2, C83.2, D2.C, J1.S, J1.SN, J2.S, J2.SN, J2.TN, JP6.2, R8.2, R12.2, R14.1, R20.2, SV1.3, SV2.4, U1.8 (VSS_2), U1.19 (VSS), U2.7 (GND), U2.18 (GND), U2.21 (GND), U2.25 (AGND), U2.26 (TEST), U3.14 (GND), U4.2 (GND), X1.GND
unnamed: C8.2, C79.+, U3.26 (AUDIO_IN)
unnamed: U2.15 (USBDP), X1.D+
unnamed: C79.-, J2.T, R14.2
unnamed: C71.1, JP2.1
unnamed: R8.1, R9.2, U3.27 (AUDIO_OUT)
unnamed: JP1.1, R21.2, R23.2
unnamed: C71.2, C73.2, U3.4 (CAP2B)
unnamed: C73.1, JP2.3
unnamed: JP2.2, U3.3 (CAP2A)
unnamed: C70.2, C72.2, U3.2 (CAP1B)
unnamed: C70.1, JP3.1
unnamed: C72.1, JP3.3
unnamed: JP3.2, U3.1 (CAP1A)
unnamed: JP4.2, SV2.2, U3.23 (POTX)
unnamed: U2.16 (USBDM), X1.D-
unnamed: R5.2, SV1.1, U1.1 (RE3/~MCLR/VPP)
unnamed: JP5.2, SV2.3, U3.24 (POTY)
unnamed: C77.-, J1.T
unnamed: C18.2, R9.1, T1.2 (B)
unnamed: C77.+, R12.1, T1.1 (E)
unnamed: D1.A, L2.2, U4.1 (SW)
unnamed: JP1.2, R22.2
unnamed: D2.A, R1.1
unnamed: D3.C, R2.2
unnamed: C1.1, F1.1, X1.VBUS
unnamed: C80.1, JP4.1
unnamed: C82.1, JP4.3
unnamed: R2.1, U2.12 (!SLEEP)
unnamed: JP6.1, X1.GND@1 (GND), X1.GND@2 (GND)
unnamed: C81.1, JP5.1
unnamed: C83.1, JP5.3
unnamed: C12.2, Q1.1 (G), R3.2
unnamed: SJ1.3, U1.15 (RC4/SDI/SDA)
unnamed: R3.1, R4.1, U2.14 (!PWREN)
unnamed: SJ1.1, U1.7 (RA5/AN4/~SS/C2OUT)
R22: R20.1, R22.1, R23.1, U4.3 (FB)
RST: SJ1.2, U3.5 (RESET)
RW: U1.12 (RC1/T1OSI/CCP2), U3.7 (R/W)
RXD: U1.17 (RC6/TX/CK), U2.5 (RXD)
TXD: U1.18 (RC7/RX/DT), U2.1 (TXD)
VCC: C3.1, C4.1, C5.1, C13.1, F1.2, Q1.2 (S), R4.2, SV1.2, U1.20 (VDD), U2.4 (VCCIO), U2.20 (VCC)

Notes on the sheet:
Audio-Out
Audio-In
Noiseblocker
optional
(PN2222)(original)
Step-Up
0,6V
R2 = R1 * (5V-0,6V)/0,6V = R1 * 7,333333
+ 9V
+ 12V
bei R20 = 1k:
12V: Rx = 19k 9V: Rx = 14k
+9V when closed
1.6
www.crazy-midi.de
P-ch

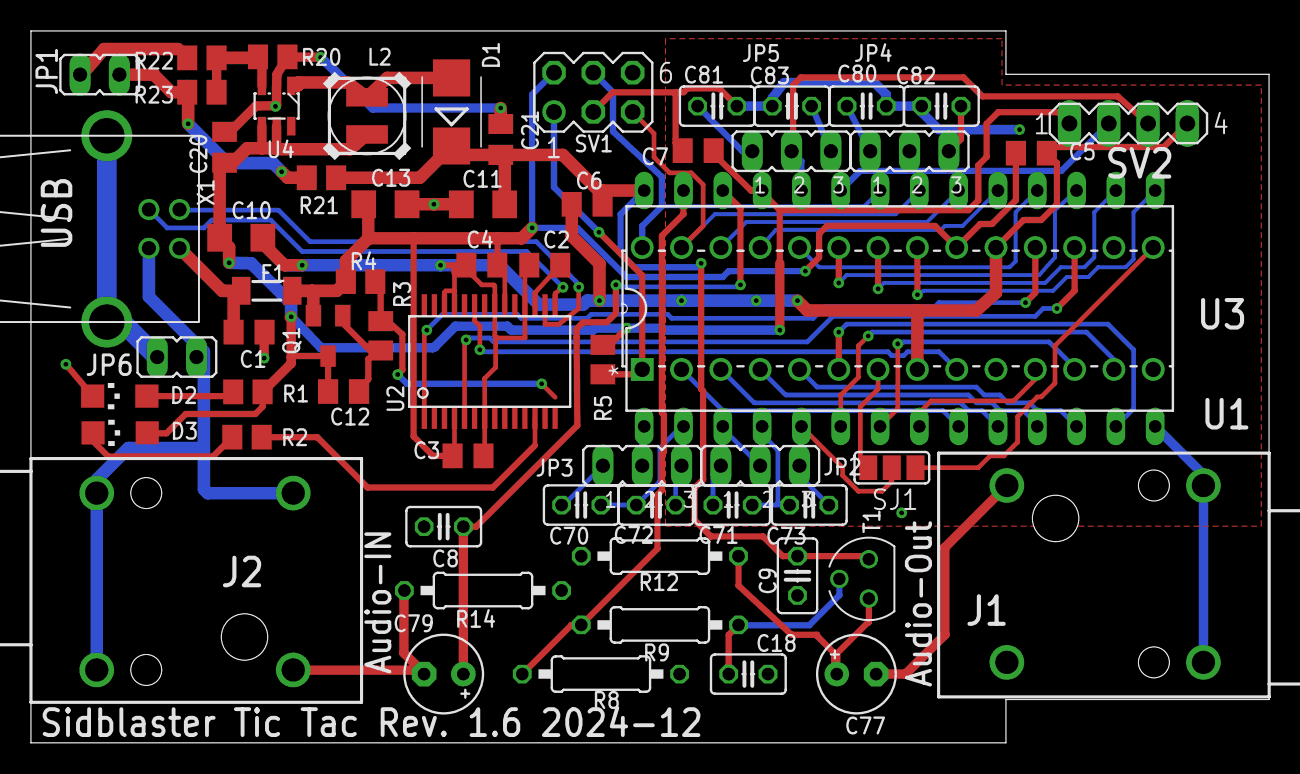
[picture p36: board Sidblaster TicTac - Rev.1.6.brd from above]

Board: 2 copper layers, 80.0 x 46.0 mm, 62 parts (0 on the bottom side), 61 nets.

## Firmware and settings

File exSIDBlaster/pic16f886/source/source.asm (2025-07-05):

; Firmware version 11 for exSID USB Rev.B
; (C) 2015-2016 T. Varene
; License: CC BY-NC-SA 4.0

; Designed for MPASM
; This program is optimized for timing accuracy, speed and size, in that order.
; Changelog at the bottom of the file.

; SIDs are driven by a timer set up to generate the 1MHz square signal. 
; Since the SID requires that read/write operations are aligned to the clock,
; the code is designed to always run an exact multiple of SID clock cycles thus
; keeping the code synchronized to the timer output.
	
; NOTE: While the SID will apparently respond to rising clock edge, some voices
; may not properly work that way. Thus clocking on falling edge (per datasheet)
; appears to be more reliable.

; This program assumes full operation within Page 0 (compatible with PIC16F722/882)
; PCLATH is preset in init routine assuming PCL is directly modified only in the address jump table
	
; This program was initially written for PIC16F88X and later adapted to PIC16F72X
; PIC16F72X support is only for "educational" purposes and is not actively supported.

	title		"exSID rev.C Firmware v11"
	
#define	FWVERS		.11
#define HWVERS		"S"


#ifdef	__16F882
	processor	16f882
	list		p=16f882
 #include		p16f882.inc
 #define		__PIC16F88X
#endif

#ifdef	__16F883
	processor	16f883
	list		p=16f883
 #include		p16f883.inc
 #define		__PIC16F88X
#endif


#ifdef	__16F886
	processor	16f886
	list		p=16f886
 #include		p16f886.inc
 #define		__PIC16F88X
#endif

; adding non-A variants left as an exercise
#ifdef	__16F722A
	processor	16f722a
	list		p=16f722a
 #include		p16f722a.inc
 #define		__PIC16F72X
#endif

#ifdef	__16F723A
	processor	16f723a
	list		p=16f723a
 #include		p16f722a.inc
 #define		__PIC16F72X
#endif

#ifdef	__16F726
	processor	16f726
	list		p=16f726
 #include		p16f726.inc
 #define		__PIC16F72X
#endif

#ifdef	__PIC16F88X
; Configuration bits
;   FOSC_EC	- enables external 24MHz clock from FTDI
;   WTDE_OFF	- watchdog is not kicked by code
;   PWRTE_ON	- power-on timer enabled
;   MCLRE_ON	- /MCLR enabled for delayed boot after secondary power rises
;   CP_OFF	- No code protection
;   CPD_OFF	- No data code protection
;   BOREN_ON	- Brown-out reset enabled
;   IESO_OFF	- Internal/external clock switchover disabled
;   FCMEN_OFF	- Fail-safe clock monitor disabled
;   LVP_OFF	- LVP disabled: frees up RB3
;   BOR40V	- Brown-out at 4.0V
;   WRT_OFF	- Write protection off
	__CONFIG _CONFIG1, _FOSC_EC & _WDTE_OFF & _PWRTE_ON & _MCLRE_ON & _CP_OFF & _CPD_OFF & _BOREN_ON & _IESO_OFF & _FCMEN_OFF & _LVP_OFF
	__CONFIG _CONFIG2, _BOR4V_BOR40V & _WRT_OFF
	
 #define SETHIBDRT	; if defined: 2Mbps, 1-cycle resolution, else 750kbps, 2-cycle resolution
#endif	;__PIC16F88X


#ifdef	__PIC16F72X
	;   BORV_25	- Brown-out at 2.5V
	__CONFIG _CONFIG1, _FOSC_EC & _WDTE_OFF & _PWRTE_ON & _MCLRE_ON & _CP_OFF & _BOREN_ON & _BORV_25 & _PLLEN_ON
 #if HWVERS == "B"
	__CONFIG _CONFIG2, _VCAPEN_RA6
 #else	; No support for VCAP on other revisions
	__CONFIG _CONFIG2, _VCAPEN_DIS
 #endif	;HWVERS

 #undefine SETHIBDRT	; 72X family can only do 750kpbs
 
 #define	ANSEL	ANSELA
 #define	ANSELH	ANSELB
 #define	EECON1	PMCON1
 #define	EEDAT	PMDATL
 #define	EEDATH	PMDATH
 #define	EEADR	PMADRL
 #define	EEADRH	PMADRH
#endif	;__PIC16F72X

#define	SIDCTL		PORTC		; SID bus control port
#define	SIDADR		PORTA		; SID bus address port
#define	SIDDAT		PORTB		; SID bus data port
#define	SIDDDR		TRISB		; SID bus data direction

#define	EXTCLK		RA7

#if HWVERS == "C" || "S"
 #define	CTLCS1		RC0
 #define	CTL_RW		RC1
 #define	CTLCS0		RC3
 #define	CTLRST		RC4
#else	; not "C"
 #if HWVERS == "B"
  #define	CTL_RW		RC0		; SID R/W on SIDCTL
  #define	CTLCS0		RC1		; SID CS0 (6581) on SIDCTL
 #else ; "A"
  #define	CTLCS0		RC0		; SID CS0 (6581) on SIDCTL
  #define	CTL_RW		RC1		; SID R/W on SIDCTL
 #endif	; HWVERS == "B"
 #define	CTLRST		RC3		; SID RST on SIDCTL
 #define	CTLCS1		RC5		; SID CS1 (8580) on SIDCTL
#endif	; HWVERS == "C" || "S"
#define	CTLCLK		RC2		; SID CLK on SIDCTL
#define	FTDIRX		RC6
#define	FTDITX		RC7
	
; By default RW is held low. The read routine must bring it back low after exec.
; Chip select bitmask.
#define	CSBBITM		(B'1' << CTLCS0 | B'1' << CTLCS1)
#define	CS0BITM		(B'1' << CTLCS0)
#define	CS1BITM		(B'1' << CTLCS1)

#define	JMPTBA		0x0700		; Jump table base address. 0x07xx stays in Page 0 and ensures no screw up with GOTO/CALL

; Cross-bank data registers
	CBLOCK	0x70
TEMPBUF					; typically holds current address
WAITCNT:2				; SID clock loop counter
CSENCTL					; CS Enable bits
CSDICTL					; CS Disable bits
LPMBYTE					; Pgm memory LSB
HPMBYTE					; Pgm memory MSB
	ENDC


; Program
	ORG	0x0
__INIT

	BANKSEL	OPTION_REG
	MOVLW	B'00000000'		; OPTION bits, nothing fancy
	MOVWF	OPTION_REG

	; Disable interrupts
	BANKSEL INTCON
	CLRF	INTCON			; Disable interrupts and clear IFs
	CLRF	PIE1			; Disable peripheral interrupts
	CLRF	PIE2			; Disable peripheral interrupts
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

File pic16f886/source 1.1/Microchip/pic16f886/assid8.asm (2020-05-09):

; ASSID [acid] Asynchronous Serial SID Interface Device
; - A 500kbps serial interface for the MOS 6501 SID
;   senseitg@hotmail.com
	
;  V1.1 (read-fix) by gh0stless 2018
;  gh0stless@t-online.de

; Designed for MPASM

; To attain the highest possible speed, the SID is driven by a timer
; set up to generate the 1MHz signal to the SID. Since the SID requires
; that read/write operations are aligned to the clock, the code loop is
; designed to always run an exact multiple of clock cycles thus keeping
; the code synchronized to the timer output.

	list			p=16f886
	radix			dec
	#include		p16f886.inc

; Configuration bits
;   INTOSCIO  - allows power up without 12MHz clock from FTDI
;	WTD_OFF   - watchdog is not kicked by code
;   MCLRE_OFF - else will require jumper on programming header
;   LVP_OFF   - frees up RB3 which is very much required
	__CONFIG _CONFIG1, _INTOSCIO & _WDT_OFF & _MCLRE_OFF & _LVP_OFF

SID_CTL	    EQU		PORTC			;SID bus control port
SID_ADDR    EQU		PORTA			;SID bus address port
SID_DATA    EQU		PORTB			;SID bus data port
SID_DDR	    EQU		TRISB			;SID bus data direction

CTL_LED     EQU		3

CTL_CLK     EQU		2			;SID Ø2  on SID_CTL
CTL_RW      EQU		1			;SID R/W on SID_CTL
CTL_CS      EQU		0			;SID CS  on SID_CTL

ADDR_SYN    EQU		7			;SYN     on SID_ADDR
ADDR_DDR    EQU		6			;DDR	 on SID_ADDR
ADDR_RST    EQU		5			;SID RST on SID_ADDR

TEMP	    EQU		0x70			;Temp memory
	
	ORG	0

	GOTO	__INIT

	ORG	4
__ISR
	RETFIE

__INIT


	BTFSC   INTCON,     GIE

	;Disable analog	
	BSF		STATUS,		RP0
	BSF		STATUS,		RP1
	CLRF	ANSEL					;ANSEL   <- 0b00000000
	CLRF	ANSELH					;ANSELH  <- 0b00000000

	;Preset data
	BCF		STATUS,		RP0
	BCF		STATUS,		RP1
	CLRF	PORTA					;PORTA   <- 0b00000000
	CLRF	PORTB					;PORTB   <- 0b00000000
	MOVLW	0x01
	MOVWF	PORTC					;PORTC   <- 0b00000001

	;Enable outputs
	BSF		STATUS,		RP0
	MOVLW	0xC0
	MOVWF	TRISA					;TRISA   <- 0b11000000: <0:4>:address <5>:rst
	MOVLW	0xFF
	MOVWF	TRISB					;TRISB   <- 0b11111111: <0:7>:data
	MOVLW	0xB0
	MOVWF	TRISC					;TRISC   <- 0b10110000: <0>:cs <1>:rw <2>:clk <3> led <6>:tx <7>:rx
	
	;Set up T1/PWM output (SID_CLK)
	MOVLW	0x77
	MOVWF	OSCCON					;Switch to 8MHz

	MOVLW	0x04
	BCF		STATUS,		RP0
	MOVWF	T2CON					;T2CON   <- 0b00000100:	T2 = sysclk
	MOVLW	0x01
	BSF		STATUS,		RP0
	MOVWF	PR2					;PR2     <- 0b00000001: reload at 1 = 2 cycles
	MOVLW	0x01
	BCF		STATUS,		RP0
	MOVWF	CCPR1L					;CCPR1L  <- 0b00000001:	pwm duty 50%
	MOVLW	0x0F
	MOVWF	CCP1CON					;CCP1CON <- 0b00001111: pwm enable @P1A/SID_CLK

	;UART setup
	BSF		STATUS,		RP0
	BSF		STATUS,		RP1
	MOVLW   0x48
	MOVWF   BAUDCTL					;BAUDCTL <- 0b01001000: Use 16bit BRG
	BCF		STATUS,		RP1
	;CLRF	SPBRG					;SPBRG   <- 0b00000000: 2000kbps @ 8Mhz
	MOVLW   3						
	MOVWF	SPBRG					;SPBRG   <- 0b00000011: 500kbps @ 8Mhz
	MOVLW	0x24					
	MOVWF	TXSTA					;TXSTA   <- 0b00100100: Enable transmitter
	BCF		STATUS,		RP0
	MOVLW	0x90
	MOVWF	RCSTA					;RCSTA   <- 0b10010000: Enable receiver

	NOP

__MAIN
	;@00:0 Wait for data
wait_for_address
	NOP
	BTFSS	PIR1,		RCIF
	GOTO	wait_for_address
	NOP

	;@04:0 Copy received byte to address port
	MOVF	RCREG,		W
	MOVWF	PORTA

	;@06:2 Ensure sync bit set - helps fix sync errors
	MOVWF	TEMP
	BTFSS	TEMP,		ADDR_SYN
	GOTO    wait_for_address

		
	;@12:0 Requesting read or write?
	BTFSC	TEMP,		ADDR_DDR
	GOTO    __WRITE_REGISTER

__READ_REGISTER
	;@18:2 Pre-align
	NOP
	;@14:2 Set data port to input
	BSF		STATUS,		RP0
	MOVLW	0xFF
	MOVWF	SID_DDR
	BCF		STATUS, 	RP0
		
	;Disable analog	
	BSF		STATUS,		RP0
	BSF		STATUS,		RP1
	CLRF		ANSELH					;ANSELH  <- 0b00000000
	BCF		STATUS,		RP0
	BCF		STATUS,		RP1
	
	
	;@18:2 SID transfer
	BSF		SID_CTL,	CTL_RW
	BCF		SID_CTL,	CTL_CS
	NOP
	
	MOVF	SID_DATA,	W
		
	;@23:3 Send
	MOVWF	TXREG
	
	BSF		SID_CTL,	CTL_CS
	BCF		SID_CTL,	CTL_RW

	;@24:0 Post-align
	NOP

	;@26:2
	GOTO	__MAIN

__WRITE_REGISTER

	BSF     SID_CTL,	CTL_LED

	;@15:3 Wait for data byte
wait_for_data
	NOP
	BTFSS	PIR1,		RCIF
	GOTO	wait_for_data

	;@18:2 Set data port to output
	BSF		STATUS,		RP0
	CLRF	SID_DDR
	BCF		STATUS, 	RP0
	
	;@21:1 Copy received byte to data port
	MOVF	RCREG,		W
	MOVWF	PORTB

	;@23:3 Pre-align

	;@23:3 SID transfer
	BCF		SID_CTL,	CTL_RW
	BCF		SID_CTL,	CTL_CS
	NOP
	BSF		SID_CTL,	CTL_CS

	BCF     SID_CTL,	CTL_LED

	;@27:3 Post-align

	;@30:2
	GOTO	__MAIN

__END
	END

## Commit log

2017-05-01 Orderlist (Reichelt.de)
    Orderlist for the Parts
    [Sidblaster TicTac Bauteilliste Rev.1.1.ods]
2018-03-02 Rev. 1.2 uploaded
    [Sidblaster TicTac - Rev.1.2.brd, Sidblaster TicTac - Rev.1.2.sch]
2018-07-17 add Assembly instructions
2018-10-12 Added FAQ with wiring Pic for Programming
    * Added wiring Pic3 SV1
    * added photo
2020-08-17 updated docs
    [Sidblaster TicTac Bauteilliste (BOM) Rev.1.2.xlsx, Sidblaster TicTac Bauteilliste Rev.1.2.ods]
2021-05-22 Rev1.3 PCB added
    [Sidblaster TicTac - Rev.1.2.brd, Sidblaster TicTac - Rev.1.2.sch, Sidblaster TicTac - Rev.1.3.brd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]
2021-05-23 Rev.1.3 small fix
    [Sidblaster TicTac - Rev.1.3.sch]
2021-06-11 The 1.3 release
    [Sidblaster TicTac Bauteilliste (BOM) Rev.1.2.xlsx, bill of materials (BOM) Rev.1.3.ods]
2022-05-05 Rev. 1.4
    [Sidblaster TicTac - Rev.1.4.brd, Sidblaster TicTac - Rev.1.4.sch, bill of materials (BOM) Rev.1.4.ods]
2022-06-06 documentation updated
    [bill of materials (BOM) Rev.1.4.ods]
2022-08-01 Add 3D-printed case (#3)
    * Add files via upload
    * Delete SIDBlaster-USB-Tic-Tac-Case-Top-V1.stl
    * Create README.md
    * Add files via upload
    * Update README.md
    [SIDBlaster-USB-Tic-Tac-Case-Bottom-V1.blend, SIDBlaster-USB-Tic-Tac-Case-Bottom-V1.stl, SIDBlaster-USB-Tic-Tac-Case-Top-No-Text-V1.blend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]
2022-09-23 PCB Rev.1.5
    [Sidblaster TicTac - Rev.1.5.sch]
2022-10-19 documantation update/rev.1.5 pcb
    [Sidblaster TicTac - Rev.1.5.brd, bill of materials (BOM) Rev.1.5.ods]
2022-10-19 doc updated
    [bill of materials (BOM) Rev.1.5.ods]
2022-10-19 Updated BOM
    [bill of materials (BOM) Rev.1.5.ods]
2023-01-02 Update Assembly Instructions
2024-10-31 Halloween 2024 Upload Production files
    [Sidblaster TicTac - Rev.1.5_top_bom-2.csv, Sidblaster TicTac - Rev.1.5_top_bom.csv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]
2024-11-23 Update Manual
    [Sidblaster TicTac - Rev.1.5_top_bom-alt.csv, Sidblaster TicTac - Rev.1.5_top_bom.csv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]
2026-08-03 Update hardsid_library to v517, remove old installer/binaries
    Replaced the old v.515beta2-era zips (2021/2023) and the bundled
    debian installer scaffold with the current v517 (0x0205) plain
    binaries. Installers are no longer bundled here or anywhere in public
    repos - see crazy-midi.de for those; this folder now just points at
    the driver's own repo/releases for anything beyond what's kept here
    for existing manual download links.
2026-08-03 Rewrite and expand main README
    Add repo layout table, getting-started steps, links to the driver/
    SIDBlasterTool/ASID Player/AIASS/NG software repos, license section
    (GPL v3 hardware+firmware, CC BY 4.0 case), and credits.
2026-08-03 Correct multi-device count: driver supports up to 8 units, not 3
2026-08-03 Expand NG rationale: scalability vs. single-device RP2040 alternatives
2026-08-03 Mention NG's studio-ready 6.3mm jack outputs
2026-08-03 Fix 6.3mm jack claim: it's the Tic Tac that has it, not NG-vs-RP2040
2026-08-03 Refresh bundled driver zips: v517 hardsid lib + SIDBlasterTool v2.0
2026-08-03 Fix NG description: existing hardware via firmware trick, not a new board
2026-08-03 Update bundled driver to v518 (reverted env-var misfeature from v517)
2026-08-04 Handbuch/Manual Rev 1.4: update install guidance, fix stale links, add exSIDBlaster section
    - hardsid.dll install instructions now recommend the driver's own
    installer (System32) as the primary path, manual per-program copy
    as the fallback - matches the software-side changes from today
    - fixed dead/outdated links: sid-object repo (now archived, replaced
    with the SIDBlaster-ASID-Player link), AIASS-Mono-VST -> AIASS-Uno-VST
    (current repo name), Galfodo's driver fork -> gh0stless's actively
    maintained fork
    - new section 3.5 documenting the exSIDBlaster hardware/firmware hack
    (was in the exSIDBlaster/ folder but never mentioned in the manual)
    - reworded anti-static bracelet mention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
2026-08-04 Replace Handbuch/Manual odt+pdf with Markdown, flatten docs/sources
    Markdown is easier to review, diff, and edit directly than odt+PDF,
    and sidesteps the ODF-XML pagination/anchoring issues found while
    fixing the previous odt source. Content and this session's fixes
    (license -> CC BY-ND 4.0, driver/middleware wording, download links
    pointed at crazy-midi.de, ACID64 no-longer-needs-driver note, DLL
    repo + integrators_guide.md reference, POSIX-port credit, Community
    section folded into Links) carried over from the odt.
    Also moved everything out of docs/sources/ up into docs/ and removed
    the now-empty sources folder - one less layer of indirection for the
    remaining odt/ods/odg source files (as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
    [bill of materials (BOM) Rev.1.3.ods, bill of materials (BOM) Rev.1.4.ods, bill of materials (BOM) Rev.1.5.ods]
